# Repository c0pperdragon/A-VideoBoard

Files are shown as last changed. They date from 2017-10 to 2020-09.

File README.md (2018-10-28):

# A-Video Board

A small FPGA board with a component video interface to directly drive
an analog monitor or TV input.
Its main purpose is to create component video / RGB mods of vintage
home computers and consoles or to provide video output for hobby projects.

It consists of the purest minimum parts necessary to have a multi-purpose
FPGA combined with a simple way to generate a YPbPr signal. After much research
I finally settled on a cheap MAX 10 device in a TQFP-144 package which I can 
solder by hand (barely). The rest of the parts are pretty cheap and quite easy to solder. 

To interface any of the vintage systems to the A-Video Board, level shifters
are necessary to translate the 5 volt to 3.3 volt for the FPGA input pins. These level
shifters can be implemented in a system specific daughter board that can be stacked
on top of the A-Video board. Any such interface board can probably be implemented in a 
simple single-sided wide-pitch PCB that can be even home-etched with some experience.

Currently I have built applications of the A-Video board for 
* [Commodore 64](/c64mod)
* [Atari 8 bit machines](/atarimod)
* [ZX Spectrum](/zxspectrummod)

## Images
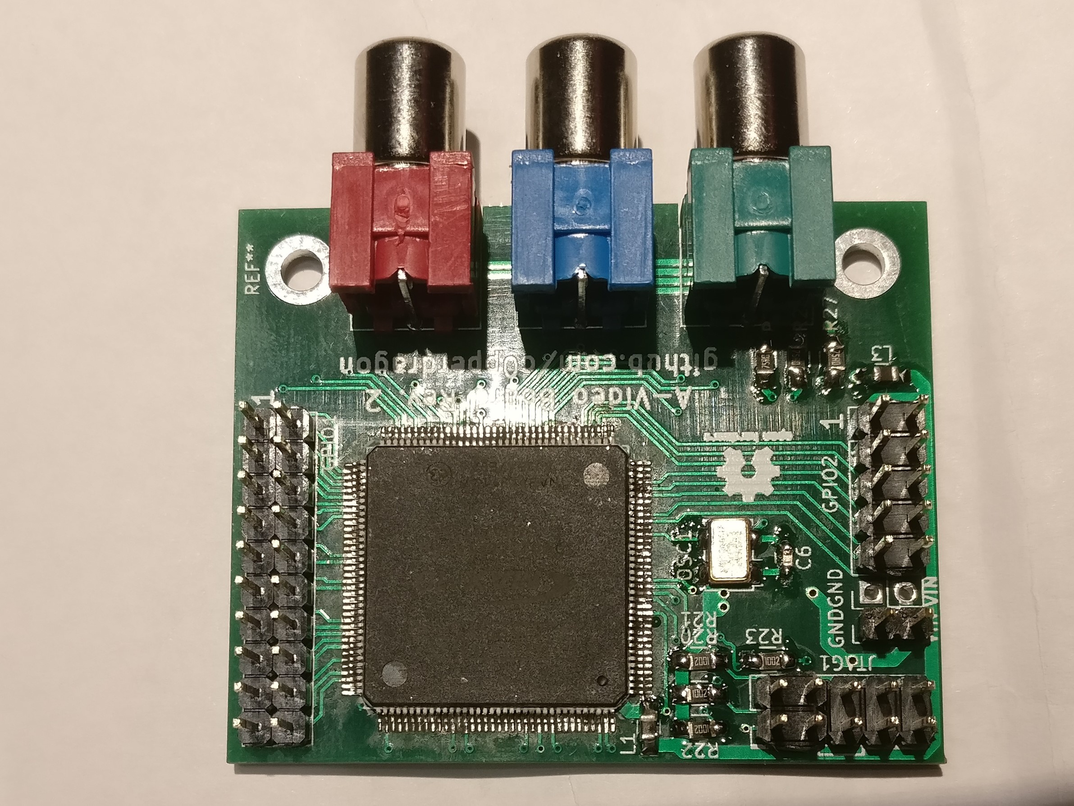
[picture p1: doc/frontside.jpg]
A-Video Board front

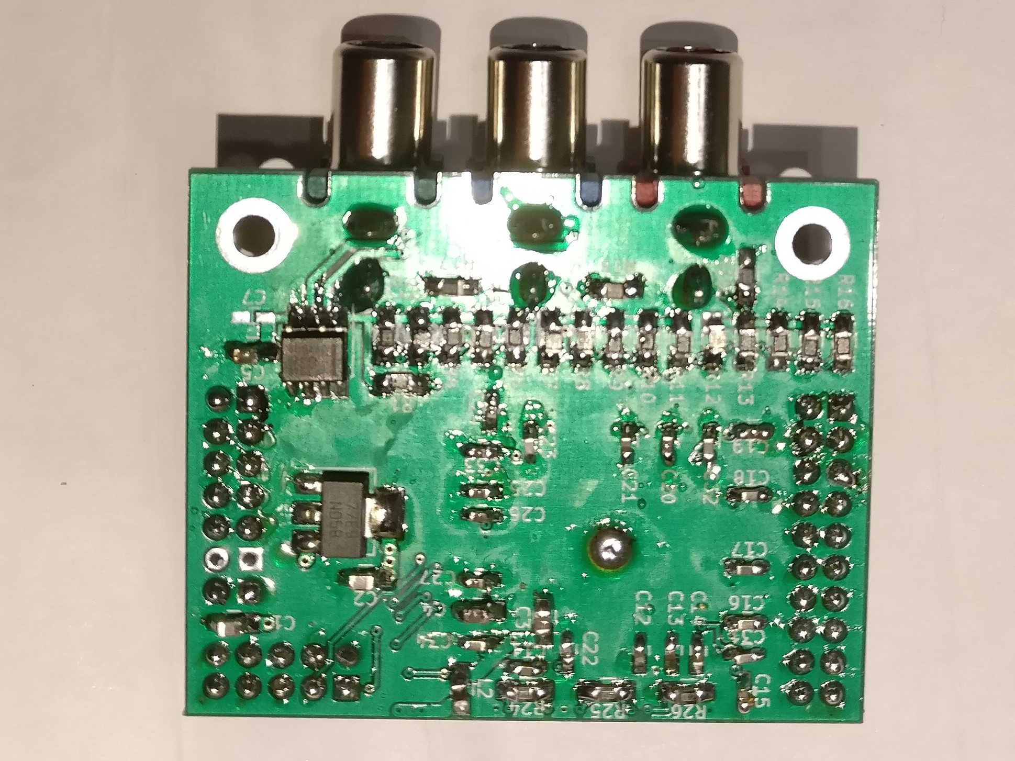
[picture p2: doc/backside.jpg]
A-Video Board back


## Board design

The board has these main parts

* 10M02SCE144: fairly cheap FPGA of the MAX10 series
* LM1117IMPX-3.3:   linear voltage regulator
* LFSPX0024957:     25Mhz clock generator
* THS7316:          video output amplifier
* R1-R19:           three 5-bit DACs made from transistors

and various supporting passive components, mainly decoupling, filtering and pull-ups.

It has the following connectors:
* GPIO1  20-pin header that directly connects to FPGA pins
* GPIO2  10-pin header with two pins providing GND and +3.3V, the remaining 8 connect to the FPGA.
* JTAG   10-pin header for programming the FPGA (via an USB-Blaster or compatible device)
* 3 RCA sockets to output the video signal (normally YPbPr, but other formats could be produced as well).
 Note that in the schematics these sockets are denoted as BNC, but are actually RCA connectors of type 
 RCJ-046 (green), RCJ-042 (red), RCJ-045 (blue).
* GND, VIN  Provide between 4.5V and 9V as supply voltage. The board consumes about 80mA.
 
## Contact
If you plan to use an A-Video board, feel free to contact me for assistance:
reinhard.grafl (at) aon.at  
Maybe I will either have some spare PCBs I could send you to populate yourself,
or even provide you with a fully assembled board for the cost of the parts and shipping.

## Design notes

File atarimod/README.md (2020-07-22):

# Atari RGB Mod

Built on the A-Video board, this is a modification usable for Atari 8-bit 
computers that generate YPbPr signal in either 288p or 576p to display on
modern displays. 

## Motivation

These old Atari computers generate the colour output signal directly in the weird way that was
necessary to construct a PAL or NTSC signal. The technique is called "quadrature amplitude modulation" and has the
disadvantage of not being completely reversible, so the original colours can not be reconstructed from this
signal.
Even worse, the XL line of machines does not even provide this signal directly on the video output, but
only already combined with the luminance signal as composite video. There are simple ways to provide 
separate luminance and colour, but even then the quality is pretty bad. 
This was not such a problem on cathode ray tube (CRT) displays, but on modern LCD TVs this signal looks totally
unusable.

So, no matter how I tried, I could not reliably re-construct the original colours from the colour signal output. 
The only way to really solve the issue was to intercept the necessary information in digital form to 
create a perfectly sharp and clear analog video signal by my own circuitry. 

## Theory of Operation

The FPGA chip passively listens to all relevant pins of the GTIA graphics chip and re-implements the 
relevant logic of the GTIA in its logic fabric, effectively providing a second GTIA (parts of it).
To sniff the signals from the GTIA, a specific adapter board is needed that sits between the 
GTIA and its socket. Revision 3 of the adapter is now pretty small and should fit in all Atari models.
From this adapter, a 20-pin ribbon cable (either mounted permanently to the adapter or using a plug)
leads to the FPGA board.
This FPGA board can either be the generic A-Video board or a re-purposed C64 Video Enhancement Board. 
Both boards are firmeware-compatible, but differ in their size and connector options. You should 
also be able to fairly easily change these connectivity options anyway.

## Adapter building details (Rev. 3)

In the doc folder, there are schematics, gerber files and a bill of material to build the adapter.
Ideally you need a 0.8mm PCB (a slighly thicker boards will also work) and assemble everything except
the P1 socket.  This specific socket is meant to be put into the big holes, so the extra-long solder tails 
will stick out pretty far on the bottom side. These will then fit into the IC socket on the Atari.
Take care not to get any solder onto these thin tails when soldering the ticker barrels into the 
adapter board (this can become tricky, but with a 0.8mm board it should not be too hard).
Before actually soldering the socket you have to cut away one of the plastic cross-beams so it
will not conflict with the ICs.

For attaching the 20-pin ribbon cable to P2, you have several options. I used an angled 
pin-header with a standard ribbon cable connector to keep a low profile. If there is space 
in your device you can as well use a straight pain-header. An even more sophisticated option
is a permantent PCB-to-ribbon-cable header which can be found with quite a low profile.
You can even solder the ribbon cable wires direcly into the board or whatever you fancy.

## FPGA Details

The FPGA on the A-Video board is programmed in VHDL, using the free version of the Quartus II development suite.
This chip has an on-board non-volatile program memory, so no external flash is needed and the chip has
a very short start-up time. There is a PLL built in which I use to generate a 228Mhz clock from the 25Mhz reference.
With this 228Mhz and some advanced  programming I can multiply the Atari pixel clock to a pretty clean (below 1 ns jitter) 14,1875 MHz clock to drive the whole circuit and create a nice output signal.

On non-PAL machines the Atari pixel clock runs at a slightly different speed. There the clock multiplier circuit will actually produce an internal clock that has variations in their clock cycle length. This will lead
to a slightly different length of every other pixel in 240p mode, and of every 4th pixel in 480p mode.

## Output

The mod can be used to create three different output formats:
* 240p/288p  (default)
* 480p/576p
* 480p/576p with scanline effect 

Selecting the output can be done by jumper connectors or an external switch (already provided 
in the C64 Video Enhancement):
* Connect GPIO2_4 to GND: 480p/576p
* Connect GPIO2_5 or GPIO2_6 to GND: 480p/576p with scanline effect

## Images
Installation of the two mod boards (Adapter Rev.2)
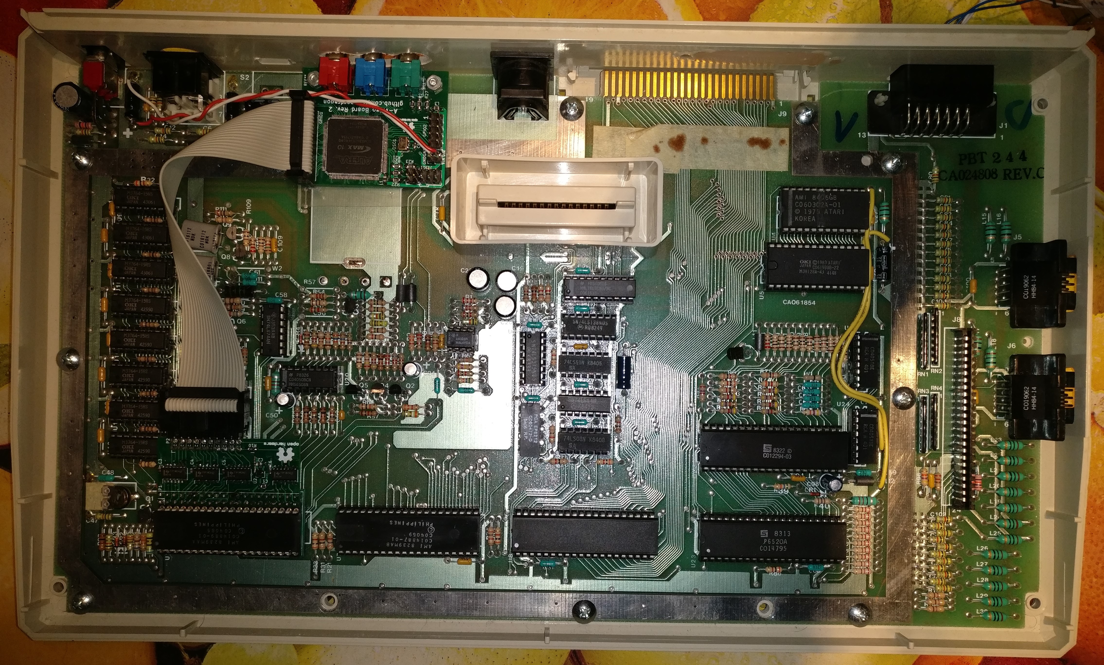
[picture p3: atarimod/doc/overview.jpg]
Overview over the whole system


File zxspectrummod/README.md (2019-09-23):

# ZXSpectrum Mod

Built on the A-Video board, this is a modification usable for the
ZX Spectrum 16K/48K versions (li'l old Speccy) that generates a
YPbPr signal in either 288p or 576p to display on modern displays.

## Motivation

As many home computers of the era, the ZX Spectrum (16K,48K) generates its
video output in the form of a composite signal that was of notoriously
bad quality, even if viewed on an analogue cathode ray tube. With 
modern LCD screens that do some digital preprocessing of the signal,
the result is even more horrible.
Even though the graphics chip (the ULA) outputs the video signal 
as a kind of RGB signal (YUV for these who know their colour formats), this
signal is still very noisy and there is a lot of digital processing
that shows up in the image. 
So this machine was also a good candidate for improvement with
my A-Video board. 

## Building

The construction uses the A-Video board with a small daughter board for shifting
the logic levels from 5V to 3.3V. 
To avoid soldering leads directly to the ULA, I took the
signals from various via points on the board - basically wherever I could
find one. In a few instances I soldered the leads to some other pins of 
various parts - but never to the ULA itself.

You may notice that the mod just fits into the tiny space that is
left in the ZX Spectrum after removing the RF modulator. That is no coincidence. 
The design of the A-Video board itself was totally driven by this exact space
constraint. 

As a side note I want to mention that I have replaced the original 
voltage regulator with its huge heat sink with a modern buck converter 
that generates nearly no heat at all. This will probably reduce the stress on the 
power supply (the original one) as well reduce the temperature in the cramped 
computer case.

## Implementation details

The FPGA chip passively listens to all relevant pins of the ULA and tries to make
sense of what is going on. 
This was not so easy as it may seem, because I was not able to directly extract the pixel
clock. There are no pins on the ULA that would directly provide this. The connection to the 
oscillator quartz is very sensitive to any added load and I could not reliably connect anything
to it without rendering the system unstable. I could also not use the clock output to the CPU 
because the ULA turns this on and off in a totally unpredictable pattern to disable CPU
access to the bus.

I figured out that it is possible to listen to the CAS line which is driven by the ULA to fetch
image data from the memory. All ULA accesses have a very distinct timing pattern and can be well
separated from the accesses that are done on behalf of the CPU. For every 8 pixels that are drawn
on the screen, the ULA fetches two bytes from the same memory row without re-sending the row
address. The FPGA always monitors these bytes and can re-construct the contents of the 
video RAM. 

With a kind of custom PLL-circuit done in the FPGA, I can generate a video output signal that
is in sync with the incoming stream of video data.

## Output

The mod can be used to create three different output formats:
* 288p (default)
* 576p
* 576p with scanlines

Selecting the output can be done by jumper connectors or an external switch:
* Connect GPIO1_18 to GPIO1_17 (or GND): 576p without scanlines
* Connect GPIO1_15 to GPIO1_17 (or GND): 576p with scanlines 

## Images
Overview over the whole system
Installation of A-Video with daughter board
Closed machine with YPbPr sockets
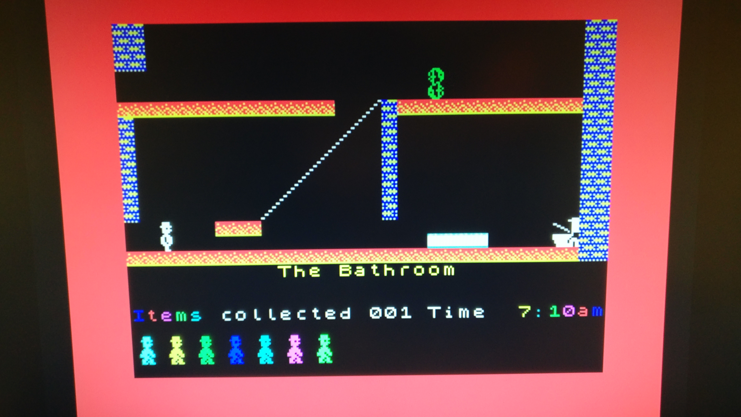
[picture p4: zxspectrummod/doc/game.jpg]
576p video output on my TV

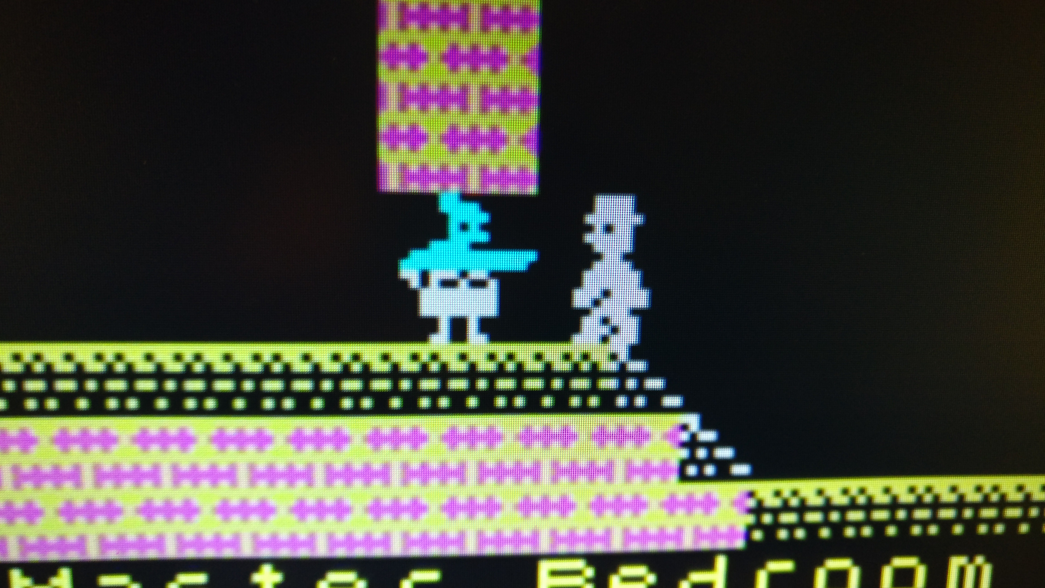
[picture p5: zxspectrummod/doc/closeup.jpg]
Closeup of video output


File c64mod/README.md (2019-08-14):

# C64 RGB Mod

Built on the A-Video board, this is a modification usable for the Commodore 64 computer
that generates a YPbPr signal in either 288p or 576p to display on modern displays.

## Motivation

I wanted to get the most perfect display from an original C64 computer. After many failed attempts to 
reconstruct a digitally perfect pixel-by-pixel display from the S-Video output, I finally came back
to my original idea to emulate the inner workings of the VIC-II chip. 
So, as for the atari 8-bit line and the ZX Spectrum, I applied my trusty A-Video board. 

## Building details

The FPGA chip passively listens to all relevant pins of the VIC graphics chip and re-implements the 
relevant logic of the GTIA in its logic fabric, effectively providing a second VIC (parts of it).
The mod board consists of two parts: A small adapter board that sits under the VIC and sniffs all relevant
pins, and the A-Video board that does the actual processing. The 5 volt signals from the C64 are
level-shifted by the adapter board down to 3.3 volts for use by the FPGA.
Since the adapter board only listens to the signals (with very high-impedience input pins), it 
will not influence the working of the VIC or any other part of the system in any way. The FPGA implementation
may have some glitches, but this should only affect the visual output.
Note that the mod consumes an additional 100mA of current from the 5 volt rail, 
so make sure that your power supply can handle this.

## Assembling the VIC adapter board

If you want to build your own adapter board, you need to have a PCB manufactured with 0.8mm thickness 
(use the gerber.zip for ordering). After soldering the ICs and passives, you need to fit a 40-pin
IC socket into the big holes. Use the socket type with round pins (the more expensive ones).
Solder from below and remove as much excess solder as possible. Then install the ribbon cable connector.
Take special care when installing the voltage regulator, as this small package always gave me the most trouble.
For your convenience, I have set up a [BOM](doc/adapterboard_bom.ods) and a parts list at 
[mouser](https://www.mouser.com/ProjectManager/ProjectDetail.aspx?AccessID=2b75b16750)
containing everything to build the board.

## Connectors

In my current build, the A-Video port is just screwed on top of the existing RF modulator.
This saved me the trouble of removing the modulator first (which would need additional circuitry to
keep the A/V output working). But this comes at the cost that the back of the computer case 
now has a rather large and ugly hole. I am pretty sure there are good solutions available to get rid of
this big modulator box while keeping the A/V functionality. Then the YPbPr connectors would be located
much lower and would look more natural.
If you even want a totally reversible mod you could probably place the A-Video board somewhere inside the
case and bring out the YPbPr cable through the user port opening.

## Output

The mod can be used to create three different output formats:
* 288p (default)
* 576p
* 576p with scanline effect

Selecting the output can be done by jumper connectors or an external switch:
* Connect GPIO2_4 to GPIO2_2 (GND): 576p
* Connect GPIO2_6 to GPIO2_2 (GND): 576p with scanline effect

## Images
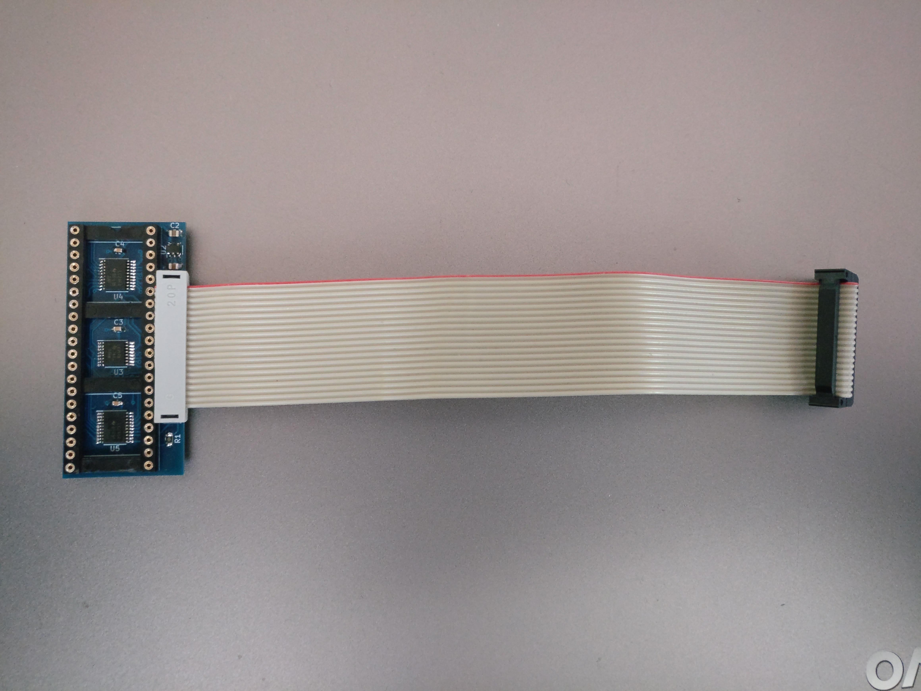
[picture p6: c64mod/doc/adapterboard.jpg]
VIC-II adapter board

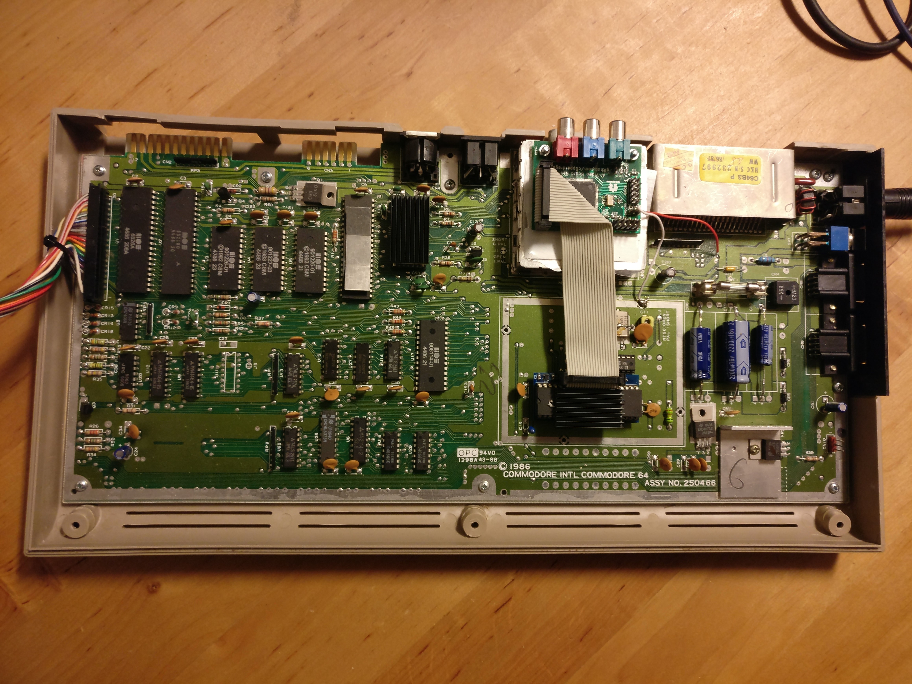
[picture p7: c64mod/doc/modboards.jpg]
Installation of the two mod boards

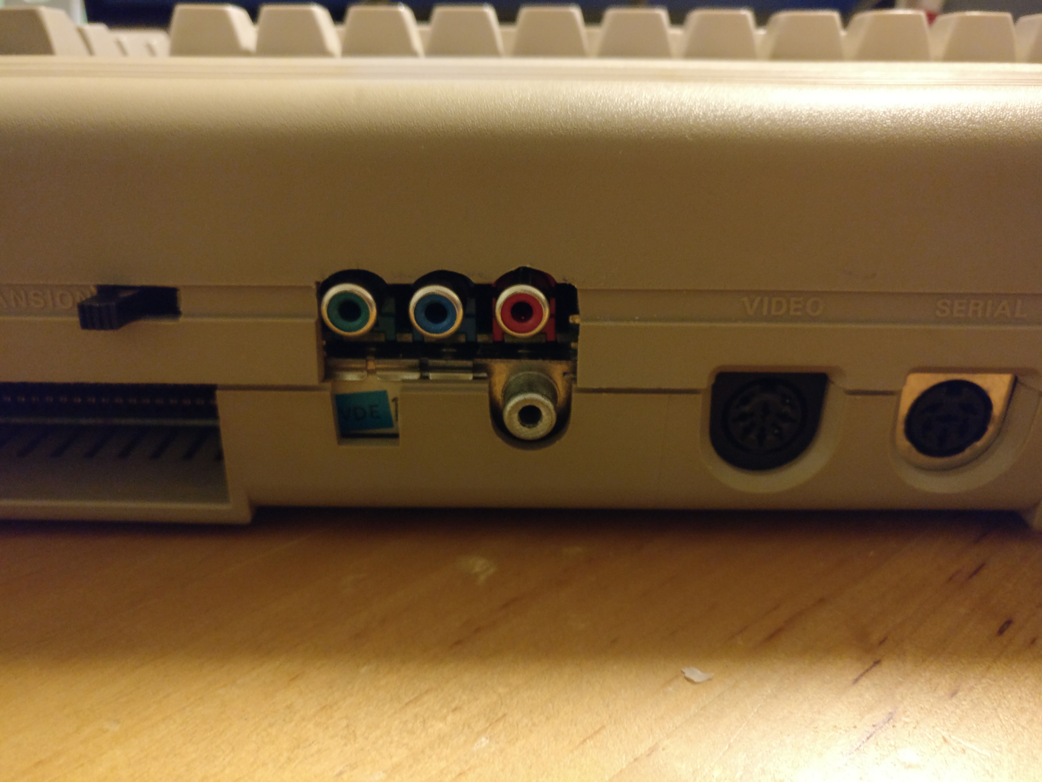
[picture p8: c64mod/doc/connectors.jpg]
Backside connectors

Display with standard definition (crappy upscaler)
Display with doubled scanlines
Display with doubled scanlines and visual scanline effect

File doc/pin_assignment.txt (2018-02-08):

Pin assignments for the A-Video Board (Rev.2)

25Mhz Reference clock:   MAX 10 pin 25

20-pin GPIO-header GPIO1
Connector pin            MAX 10 pin       
GPIO1 1                  74
GPIO1 2                  75
GPIO1 3                  76
GPIO1 4                  77
GPIO1 5                  78
GPIO1 6                  79
GPIO1 7                  80
GPIO1 8                  81
GPIO1 9                  87
GPIO1 10                 88
GPIO1 11                 91
GPIO1 12                 92
GPIO1 13                 97
GPIO1 14                 98
GPIO1 15                 99
GPIO1 16                100
GPIO1 17                101
GPIO1 18                103
GPIO1 19                105
GPIO1 20                106

10-pin GPIO-header GPIO2
Connector pin            MAX 10 pin       
GPIO2 1                  3.3V
GPIO2 2                  GND
GPIO2 3                  41
GPIO2 4                  40
GPIO2 5                  39
GPIO2 6                  33
GPIO2 7                  32
GPIO2 8                  31
GPIO2 9                  28 (can drive PLL)
GPIO2 10                 27 (can drive PLL)

In-board wiring of the MAX 10 to the DAC
                         MAX 10 pin
Y(5) = SYNC              46
Y(4)                     47
Y(3)                     48
Y(2)                     49
Y(1)                     50
Y(0)                     51
PB(4)                    52
PB(3)                    53
PB(2)                    59
PB(1)                    60
PB(0)                    61
PR(4)                    63
PR(3)                    65
PR(2)                    67
PR(1)                    69
PR(0)                    70

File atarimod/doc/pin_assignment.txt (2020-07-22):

Pin assignments for the Atari mod

GTIA pin      Mod board out   A-Video board     MAX 10 pin
A1            P2 1            GPIO1 1           74
A2            P2 2            GPIO1 2           75 
A0            P2 3            GPIO1 3           76
A3            P2 4            GPIO1 4           77
D3            P2 5            GPIO1 5           78
A4            P2 6            GPIO1 6           79 
D2            P2 7            GPIO1 7           80 
D4            P2 8            GPIO1 8           81 
D1            P2 9            GPIO1 9           87 
D5            P2 10           GPIO1 10          88
D0            P2 11           GPIO1 11          91   
D6            P2 12           GPIO1 12          92
AN0           P2 13           GPIO1 13          97
D7            P2 14           GPIO1 14          98
AN1           P2 15           GPIO1 15          99
RW            P2 16           GPIO1 16         100
AN2           P2 17           GPIO1 17         101
CS            P2 18           GPIO1 18         103
PHI2          P2 19           GPIO1 19         105
HALT          P2 20           GPIO1 20         106

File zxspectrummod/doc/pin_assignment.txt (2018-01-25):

Pin assignments for the ZX-Spectrum mod (Rev.2)

Mod board in   Mod board out    A-Video board       MAX 10 pin
D7             OUT1 1           GPIO1 14            98
D6             OUT1 2           GPIO1 12            92
D5             OUT1 3           GPIO1 10            88
D4             OUT1 4           GPIO1 8             81
D3             OUT1 5           GPIO1 6             79
D2             OUT1 6           GPIO1 4             77
D1             OUT1 7           GPIO1 2             75
D0             OUT2 2           GPIO2 3             41
CAS            OUT2 3           GPIO2 5             39
IOREQ          OUT2 4           GPIO2 7             32
WR             OUT2 5           GPIO2 9             28

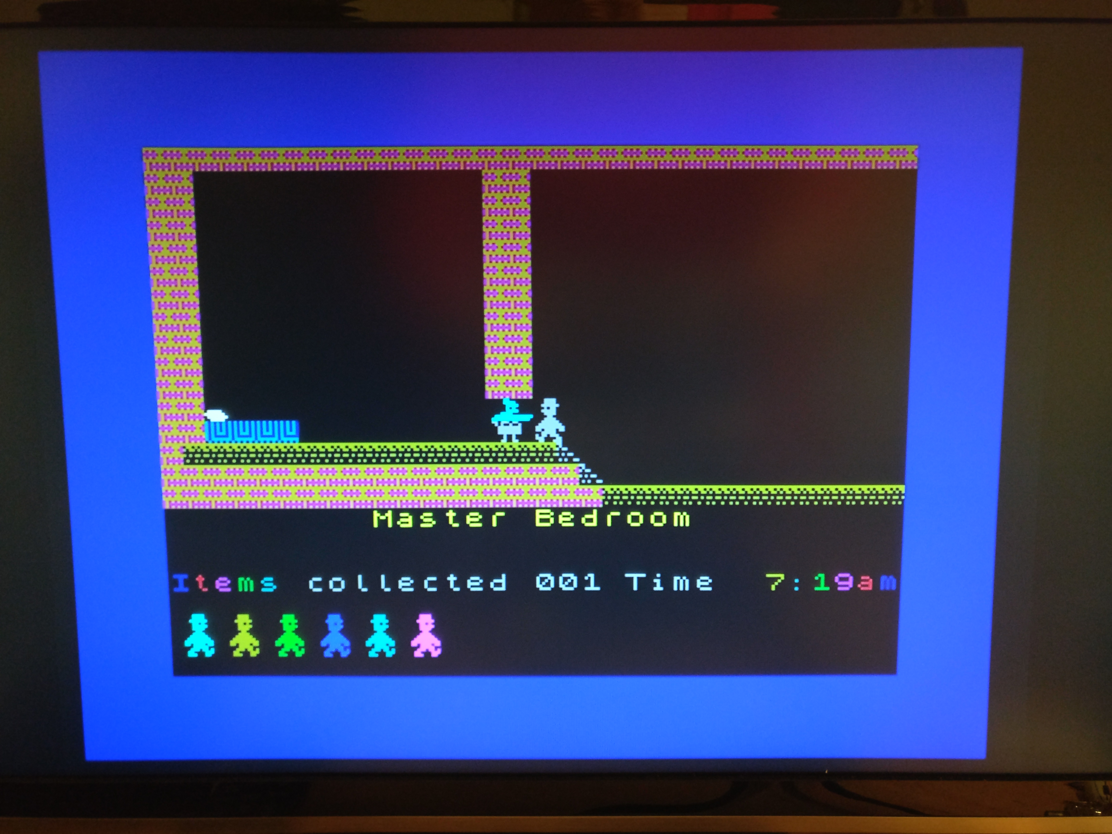
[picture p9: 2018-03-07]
zxspectrummod/doc/game288p.jpg

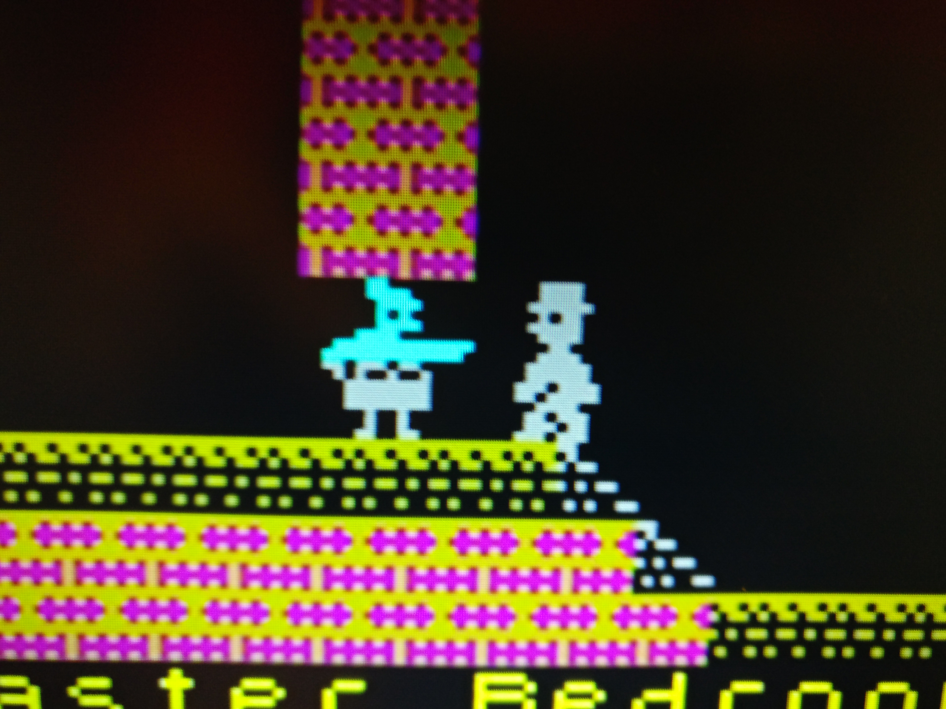
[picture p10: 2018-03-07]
zxspectrummod/doc/closeup288p.jpg

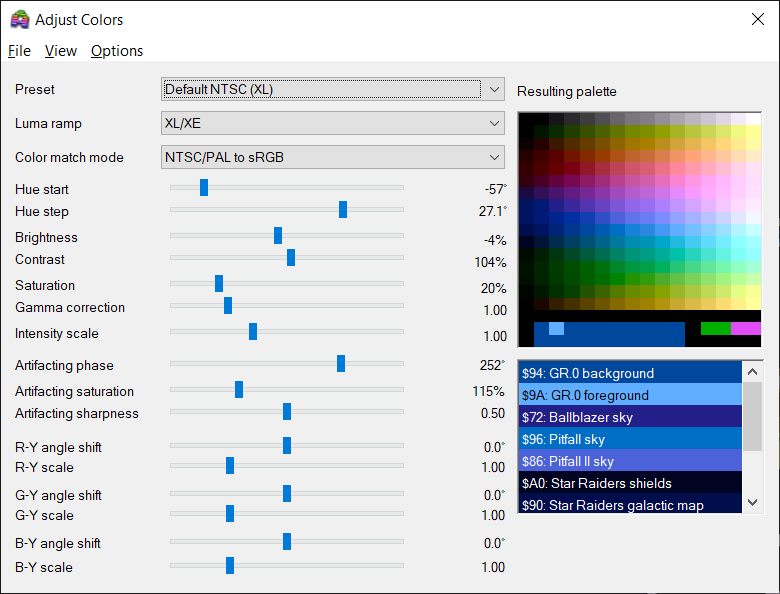
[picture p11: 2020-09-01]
atarimod/palette/Altirra Default NTSC.png

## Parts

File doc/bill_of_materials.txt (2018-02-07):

Reference, Value, Footprint, Datasheet
POWER1,CONM_01x02,Pin_Headers:Pin_Header_Straight_1x02_Pitch2.54mm,
C6,100nF,Capacitors_SMD:C_0603_HandSoldering,
C15,100nF,Capacitors_SMD:C_0603_HandSoldering,
C16,100nF,Capacitors_SMD:C_0603_HandSoldering,
C17,100nF,Capacitors_SMD:C_0603_HandSoldering,
C14,100nF,Capacitors_SMD:C_0603_HandSoldering,
C13,100nF,Capacitors_SMD:C_0603_HandSoldering,
C12,100nF,Capacitors_SMD:C_0603_HandSoldering,
C11,100nF,Capacitors_SMD:C_0603_HandSoldering,
C18,100nF,Capacitors_SMD:C_0603_HandSoldering,
C19,100nF,Capacitors_SMD:C_0603_HandSoldering,
C20,100nF,Capacitors_SMD:C_0603_HandSoldering,
C21,100nF,Capacitors_SMD:C_0603_HandSoldering,
C22,100nF,Capacitors_SMD:C_0603_HandSoldering,
C23,100nF,Capacitors_SMD:C_0603_HandSoldering,
C24,100nF,Capacitors_SMD:C_0603_HandSoldering,
C33,100nF,Capacitors_SMD:C_0603_HandSoldering,
C32,100nF,Capacitors_SMD:C_0603_HandSoldering,
C31,100nF,Capacitors_SMD:C_0603_HandSoldering,
C34,100nF,Capacitors_SMD:C_0603_HandSoldering,
C25,100nF,Capacitors_SMD:C_0603_HandSoldering,
U2,10M02SCE144,footprints:QFP_144_GND,
JTAG1,CONN_02X05,Pin_Headers:Pin_Header_Straight_2x05_Pitch2.54mm,
R23,10k,Resistors_SMD:R_0805_HandSoldering,
R21,10k,Resistors_SMD:R_0805_HandSoldering,
R20,10k,Resistors_SMD:R_0805_HandSoldering,
R22,10k,Resistors_SMD:R_0805_HandSoldering,
R24,10k,Resistors_SMD:R_0805_HandSoldering,
R26,10k,Resistors_SMD:R_0805_HandSoldering,
R25,10k,Resistors_SMD:R_0805_HandSoldering,
C1,10uF,Capacitors_SMD:C_0805_HandSoldering,
C2,10uF,Capacitors_SMD:C_0805_HandSoldering,
L2,10uH,Capacitors_SMD:C_0805_HandSoldering,
L1,10uH,Capacitors_SMD:C_0805_HandSoldering,
C3,10uF,Capacitors_SMD:C_0805_HandSoldering,
C4,10uF,Capacitors_SMD:C_0805_HandSoldering,
AMP1,THS7316,Housings_SOIC:SOIC-8_3.9x4.9mm_Pitch1.27mm,
R29,75,Resistors_SMD:R_0805_HandSoldering,
R28,75,Resistors_SMD:R_0805_HandSoldering,
R27,75,Resistors_SMD:R_0805_HandSoldering,
C7,100nF,Capacitors_SMD:C_0603_HandSoldering,
R16,16k,Resistors_SMD:R_0805_HandSoldering,
R15,8k,Resistors_SMD:R_0805_HandSoldering,
R14,4k,Resistors_SMD:R_0805_HandSoldering,
R13,2k,Resistors_SMD:R_0805_HandSoldering,
R12,1k,Resistors_SMD:R_0805_HandSoldering,
R19,150,Resistors_SMD:R_0805_HandSoldering,
R11,16k,Resistors_SMD:R_0805_HandSoldering,
R10,8k,Resistors_SMD:R_0805_HandSoldering,
R9,4k,Resistors_SMD:R_0805_HandSoldering,
R8,2k,Resistors_SMD:R_0805_HandSoldering,
R7,1k,Resistors_SMD:R_0805_HandSoldering,
R18,150,Resistors_SMD:R_0805_HandSoldering,
R6,16k,Resistors_SMD:R_0805_HandSoldering,
R5,8k,Resistors_SMD:R_0805_HandSoldering,
R4,4k,Resistors_SMD:R_0805_HandSoldering,
R3,2k,Resistors_SMD:R_0805_HandSoldering,
R2,1k,Resistors_SMD:R_0805_HandSoldering,
R17,150,Resistors_SMD:R_0805_HandSoldering,
R1,1k1,Resistors_SMD:R_0805_HandSoldering,
REG1,LM1117IMPX-3.3,TO_SOT_Packages_SMD:SOT-223,
GPIO2,CONN_02X05,Pin_Headers:Pin_Header_Straight_2x05_Pitch2.54mm,
C26,100nF,Capacitors_SMD:C_0603_HandSoldering,
C27,100nF,Capacitors_SMD:C_0603_HandSoldering,
POWER2,CONN_02X01,Pin_Headers:Pin_Header_Straight_1x02_Pitch2.54mm,
Y1,BNC,footprints:RCA_JACK,
PB1,BNC,footprints:RCA_JACK,
PR1,BNC,footprints:RCA_JACK,
GPIO1,CONN_02X10,Pin_Headers:Pin_Header_Straight_2x10_Pitch2.54mm,
OSC1,LFSPXO024957,Oscillators:Oscillator_SMD_EuroQuartz_XO53-4pin_5.0x3.2mm_HandSoldering,
L3,10uH,Capacitors_SMD:C_0805_HandSoldering,
C5,10uF,Capacitors_SMD:C_0805_HandSoldering,

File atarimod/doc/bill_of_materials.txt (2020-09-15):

References       Type                                                 Value/Part Number      Size

C1,C2            Ceramic Capacitor                                    1 uF                   2012 metric
C3,C4,C5,C6      Ceramic Capacitor                                    100 nF                 1608 metric
IC1,IC2,IC3,IC4  Schmitt-Trigger Inverter                             SN74LVC14ADBR          SSOP-14
P1               40-pin IC precision socket with long solder tails    111-93-640-41-001000   DIP 40
P2               Pinheader/Ribbon cable connector                     any                    2x20, 2.54mm 
R10              SMD Resistor                                         100 ohm                2012 metric
U2               LDO Voltage Regulator 3.3V                           MIC5504-3.3YM5         SOT-23-5

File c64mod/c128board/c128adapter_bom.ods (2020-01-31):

Manufacturer | Manufacturer Number | Designator | Qty | Description | Case | SMD/ TH | PCB side | Comments
Mill-Max | 111-93-640-41-001000 | U1 | 1 | IC & Component Sockets 40P LONG SOLDER TAIL |  | TH | Top | Unusual assembly
Mill-Max | 111-93-308-41-001000 | U1 | 1 | IC & Component Sockets 8P LONG SOLDER TAIL |  | TH | Top | Unusual assembly
Microchip | MIC5504-3.3YM5-TR | U2 | 1 | LDO Voltage Regulators Single 300mA LDO | SOT-23-5 | SMD | Top
Texas Instruments | SN74LVC257APWR | U3 | 1 | Multiplexer | TSSOP-16 | SMD | Top
Texas Instruments | SN74LVC245APWR | U4,U5 | 2 | Bustransceiver Tri-State Octal Bus | TSSOP-20 | SMD | Top
any |  | C1,C2 | 2 | Ceramic capacitor 10uF, 10%, 16V | 2012 | SMD | Top
any |  | C3,C4,C5 | 3 | Ceramic capacitor 100nF, 10%, 16V | 1608 | SMD | Top
any |  | R1 | 1 | Thick film resistor, 100 Ohm, 1% | 2012 | SMD | Top
HARTING | 9181209622 | J1 | 1 | PCB to ribbon cable connector 20P 2 ROW |  | TH | Top | Can also be other manufacturer
any |  |  | 1 | Ribbon cable, 20 leads, 1,27mm pitch, Length: 13cm |  |  | not on PCB
any |  |  | 1 | Ribbon cable connector, 20 pins (2x10) female, 2.54mm pitch |  |  | not on PCB | gold plated contacts if possible

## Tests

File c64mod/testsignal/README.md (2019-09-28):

Everything needed in a nice box

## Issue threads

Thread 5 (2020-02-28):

User feedback and experience

c0pperdragon, 2020-02-28:
Please let the community know how this device works for you, what the pitfalls were and maybe upload some pictures as well.

olliraa, 2020-03-01:
Just finished installing the A-videoboad into my ZX48k. My Speccy is an Issue 2 one with the following modifications/repairs:

-All caps replaced.
-A-videoboard installed and RF tank removed
-The infamous 7805 regulator replaced with a DC-DC step down converter pcb -> way less heat and more juice :)
-128k RAM with added GAL logic board -> this is 100% 128K Speccy compliant unlike the more simple "just add ram chips" mods. All RAM chips are also socketed now.
-vLA82 ULA replacement (original was somewhat broken)

The picture quality with the A-videoboard is simply amazing. My Speccy is connected to Sony BVM20F1E -> happy times :)

I just got the computer case closed (pun intended), which with the mod is kinda challenging, but doable. I'll add some pictures afterwards.

Just a few tips, how I solved some challenges. The original designer of the board kindly gave me some really good advice during my modding experience:

-Tap the D0-D7 signals directly from the RAM chips (pin 14) respectively. D7 is the left most chip.
-I tapped the WR, IQREQ and CAS signals directly from the ULA *under* the pcb = socket solder points. There's enough room fr the wires to go around the pcb back and actually the wire length is exactly the same as when tapping these signals from top of the pcb. Not the prettiest solution, but secure and solid :)

Closed 2022-12-13.

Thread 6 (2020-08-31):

TRRS suggestion

IanSB, 2020-08-31:
The TRRS option used on the C64 board works well so it might be worth replacing the three RCA connectors on the A VideoBoard with multiple TRRS connector positions wired in parallel so you can choose where to fit the TRRS connector depending on the position of the modultator output.

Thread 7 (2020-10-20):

Atari 5200

Icelvlan88, 2020-10-20:
Hello,

I see the Atari 5200 Sophia RGB is compatible with Atari 400, not sure if it a different board than the 5200 one. Do you think yours is compatible with 5200?

c0pperdragon, 2020-10-20:
I am pretty sure this should work. The 5200 is basically identical to the other machines of the 8-bit series in regards of its video system.

Icelvlan88, 2020-10-20:
Can this board output RGBs? Is it the same as the c64 board or this is something completely different?

c0pperdragon, 2020-10-22:
The A-Video board, when running the Atari firmware, can be jumpered to output RGsB. This may be already anough for you if your monitor can accept RGsB instead of RGB (most do ignore the sync pulses on the G line without problem) and you can additionally use the standard composite video signal as sync source.

If you have more specific demands on your signals, you can also desolder R1 from the FPGA board. This removes the sync signal from the G line and you can instead directly grab the pure sync pulse from the solder pad of R1 located nearer to the FPGA. It is a 3.3V level signal, so it should be compatible with anything that accepts TTL levels.

Icelvlan88, 2020-10-23:
I thought TTL was 5V is there a way to make the voltage higher? also this is a different board than c64 board correct?

c0pperdragon, 2020-10-23:
Oops - I was mistaken. The Atari mod firmware does not support RGsB at all. It will only ever output YPbPr.
There is a jumper option to output a very different digital signal for use with the RGBtoHDMI upscaler, but this is no use for a direct connection to an RGB monitor.

The A-Video board hardware itself is basically identical to the C64 component video mod board. It only has different output connectors (RCA instead of TRRS) and lacks the analog circuit needed for the C64.  So you can easily use a C64 mod for the Atari when flashing the Atari firmware.

If you really, really, really want an RGB option, I could modify the firmware.

Icelvlan88, 2020-10-23:
I was considering trying to use this if it work for an Atari 5200. The reason I prefer RGB is the way it looks through the framemeister and I typically use Genesis 2 RGB cables which use TTL.

c0pperdragon, 2020-10-24:
So I guess, it is your intention to build a Genesis 2 - compatible A/V port into your atari 5200. This is a pretty cool idea to re-use the rest of your setup.

When your genesis cable has the usual 470 Ohm attenuation resistor for the csync line, it will happily accept any digital sync signal between 2V and 7V. Below the 2V the sync may no longer be reliably detectable and above 7V it may become dangerous to the receiver.  With a 3.3V digital sync signal you are absolutely fine here.

A second matter are probably the 75 Ohm attenuation resistors that also seem to be built into the cable on the R, G, B lines. I am not sure about this, but the schematics for the cable I quickly found all have these.  So to avoid the picture to be to dark you would need to bridge the 75 Ohm resistors on the FPGA board to compensate for that.
It seems that the genesis console ommited the usual 75 Ohm output driver resistors which where then built into the cable.

I am positive now that I will actually add an RGsB output mode to the firmware anyway for exactly this kind of use cases.

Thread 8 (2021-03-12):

Test pattern

Zer02dk, 2021-03-12:
How is the test pattern suppose to look?
Mine looks strange, any ideas what could be the issue?

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

c0pperdragon, 2021-03-12:
The top left should be a rectangle with the 256 lum/hue combinations of Atari machined. Then there is a bar with the 16 colors of the C64. Then some moving lines. Below are three gradients with 32 steps each. One for Y one for Pb, one for Pr.
In your image it seems that all your DAC resistor networks are completely wrong/unsoldered/shorted. Or your monitor has a digital input.

Zer02dk, 2021-03-12:
I forgot to mention I'm using the RGBtoHDMI by hoglet67. But it could very well be my SMD soldering skills.

c0pperdragon, 2021-03-12:
OK, this is a completely different matter then.
The RGBtoHDMI can not convert just any analog YPbRP or RGB signal to HDMI. Basically it needs to get this in a kind of digitial or quantized form very specific to the machine in question.
This test pattern generator is just for use with "normal" YPbPr displays and will not work with the RGBtoHDMI.

I you use the A-VideoBoard in one of my supported machines (C64/C128, Atari 8bit, ZX Spectrum), then it can be configured (with jumper links) to generate such a quantized output signal. I guess there is no proper documention on this feature in the projects yet. Tell me which machine you are using the board and I can give you better instructions.

Zer02dk, 2021-03-13:
Ah, Im installing it in a C64. My bord is the one from your "C64-Video-Enhancement" project.
I havent installed it yes i wanted to test the bord first. But let me try and install it first. Just need to desolder that VICII chip.
Would you be intrested in my excess bare PCB's? I have 4 sets.

c0pperdragon, 2021-03-13:
Thank you, but I don't intend to build any more of these sets as they are now readily available from videogameperfection.com

About the testpattern: considering that you did the upscaling with the RGBtoHDMI this looks pretty OK. I would expect these kind of quantization result.

Zer02dk, 2021-03-18:
Finally got the C64 finished, and all seams to be working.

Closed 2021-03-18.

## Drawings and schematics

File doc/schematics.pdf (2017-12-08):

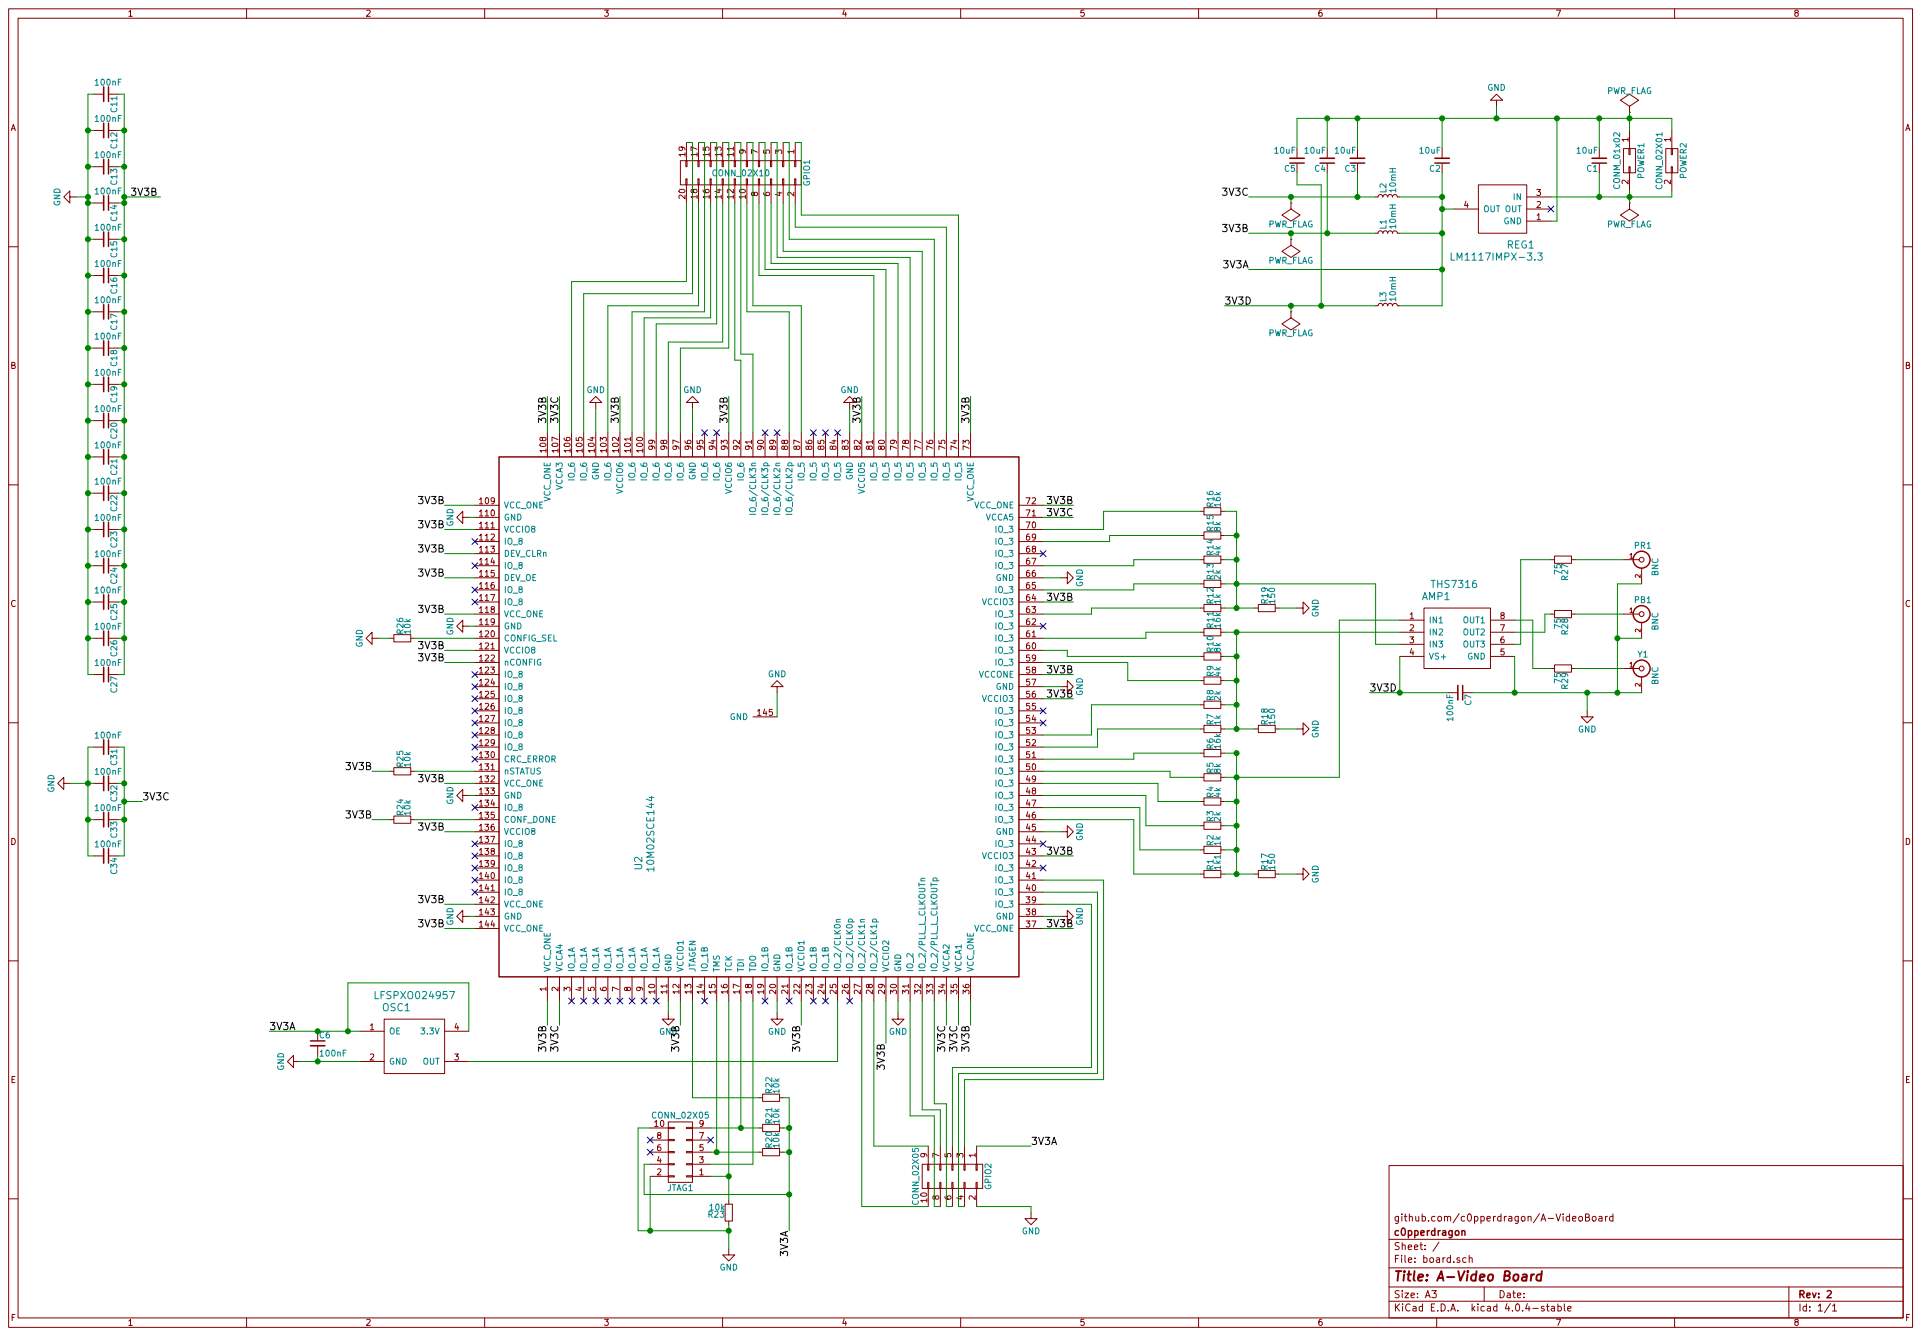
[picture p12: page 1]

File: board.sch Sheet: / c0pperdragon

Id: 1/1 Title: A-Video Board

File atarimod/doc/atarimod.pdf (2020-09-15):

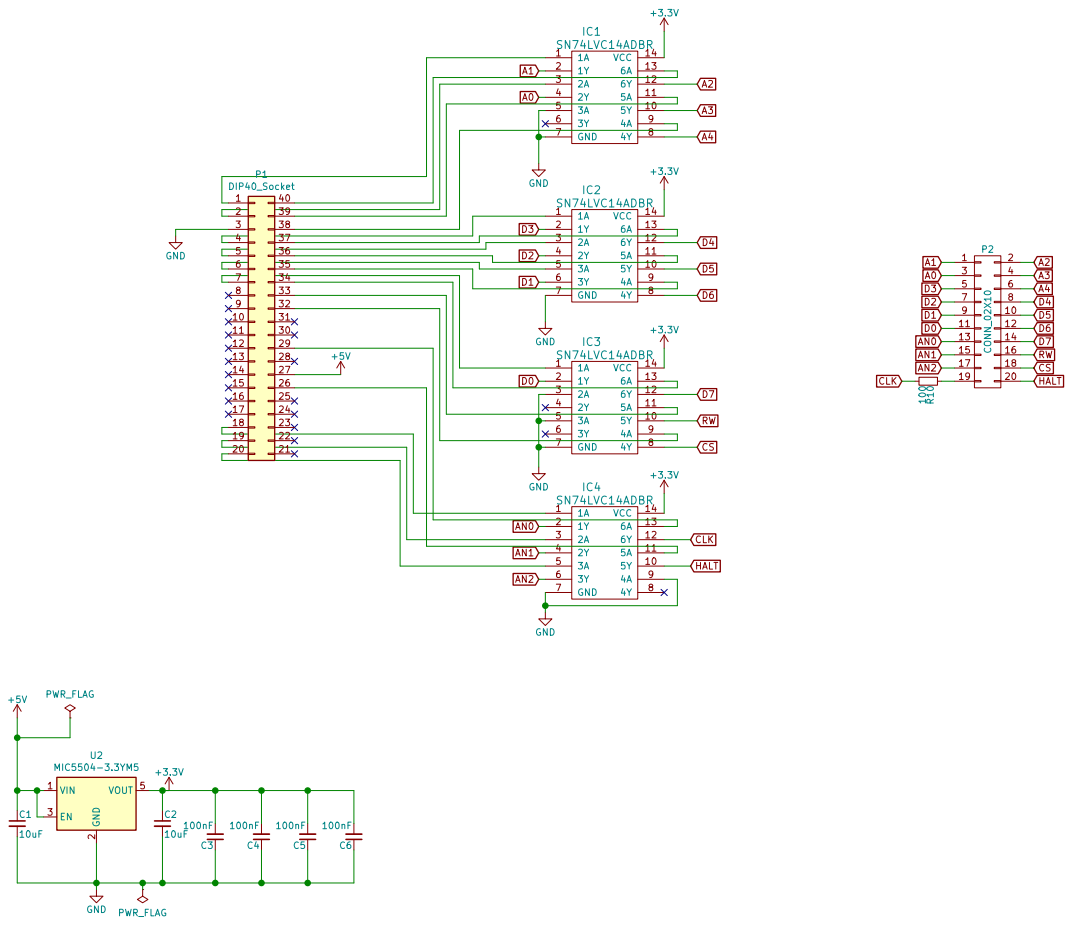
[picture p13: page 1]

+3.3V GND GNDGND GND GND

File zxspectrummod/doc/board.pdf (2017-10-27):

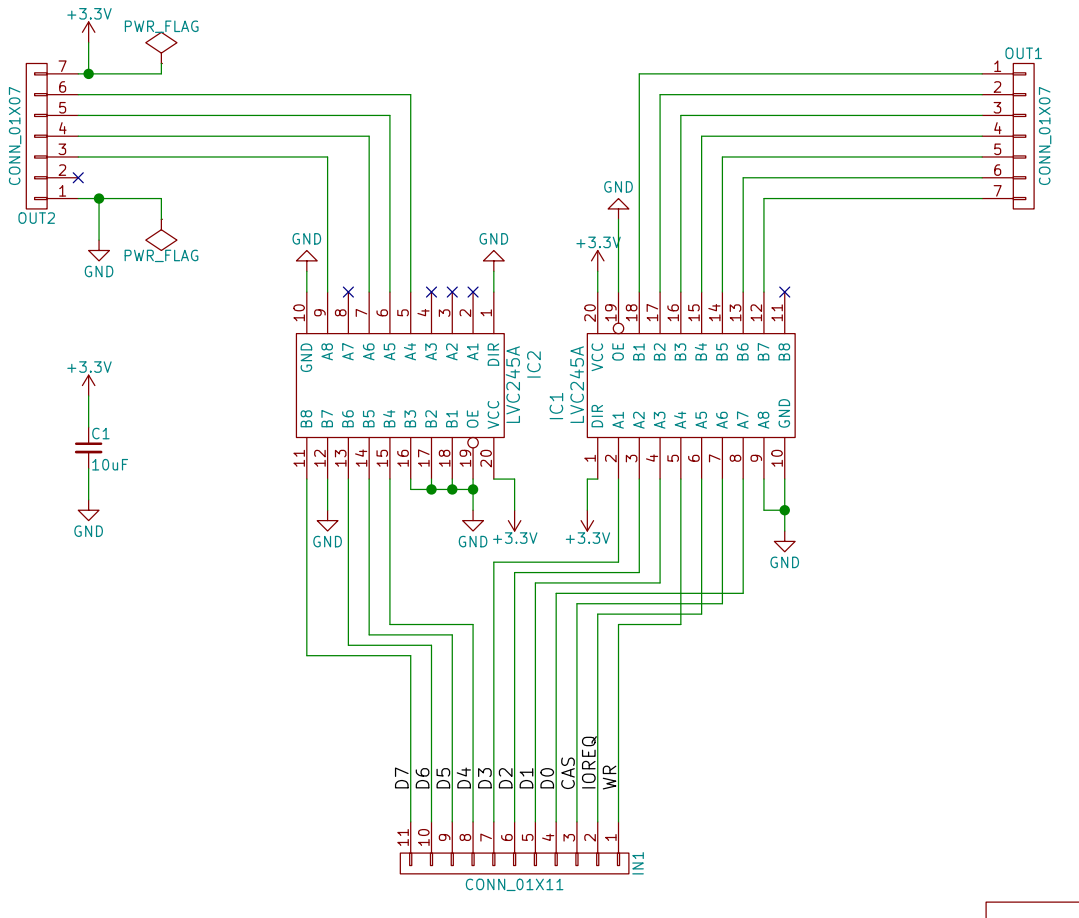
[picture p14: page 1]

9 GND 10 VCC 20 B8 11 B7 12 B6 13 B5 14 B4 15 B3 16 B2 17 B1 18 OE 19 IC2 LVC245A DIR

github.com/c0pperdragon/A-VideoBoard
File: board.sch Sheet: / c0pperdragon

Id: 1/1 Title: ZX Spectrum Mod

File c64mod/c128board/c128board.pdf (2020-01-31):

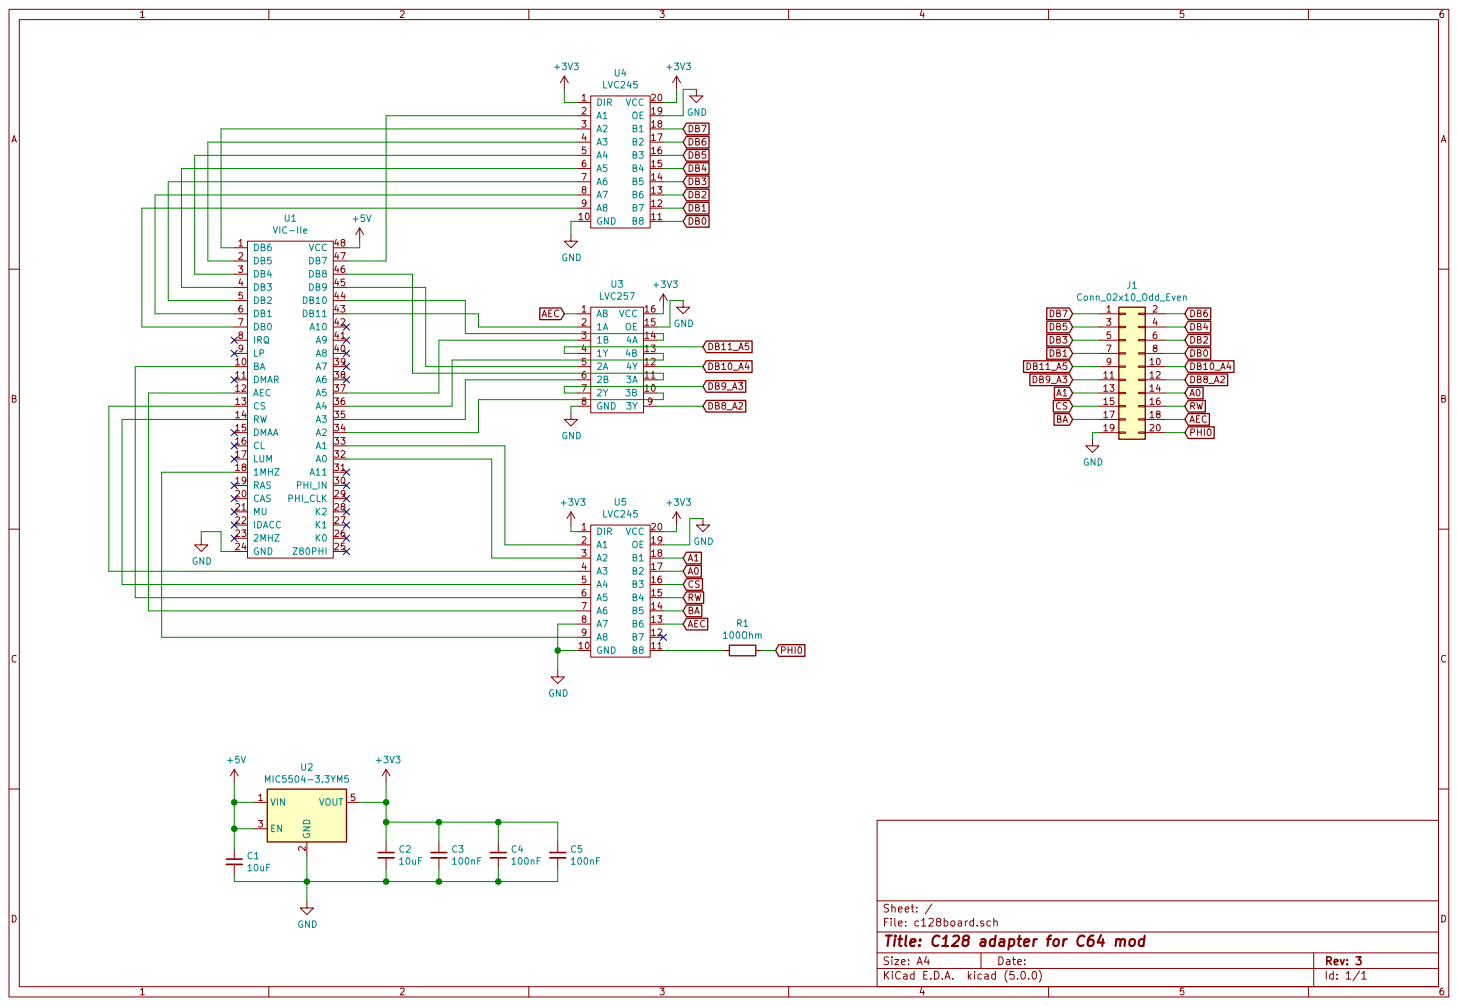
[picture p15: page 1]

2A 5 4Y | 12
2B 6 3A 3B | 11 10

Id: 1/1 Title: C128 adapter for C64 mod

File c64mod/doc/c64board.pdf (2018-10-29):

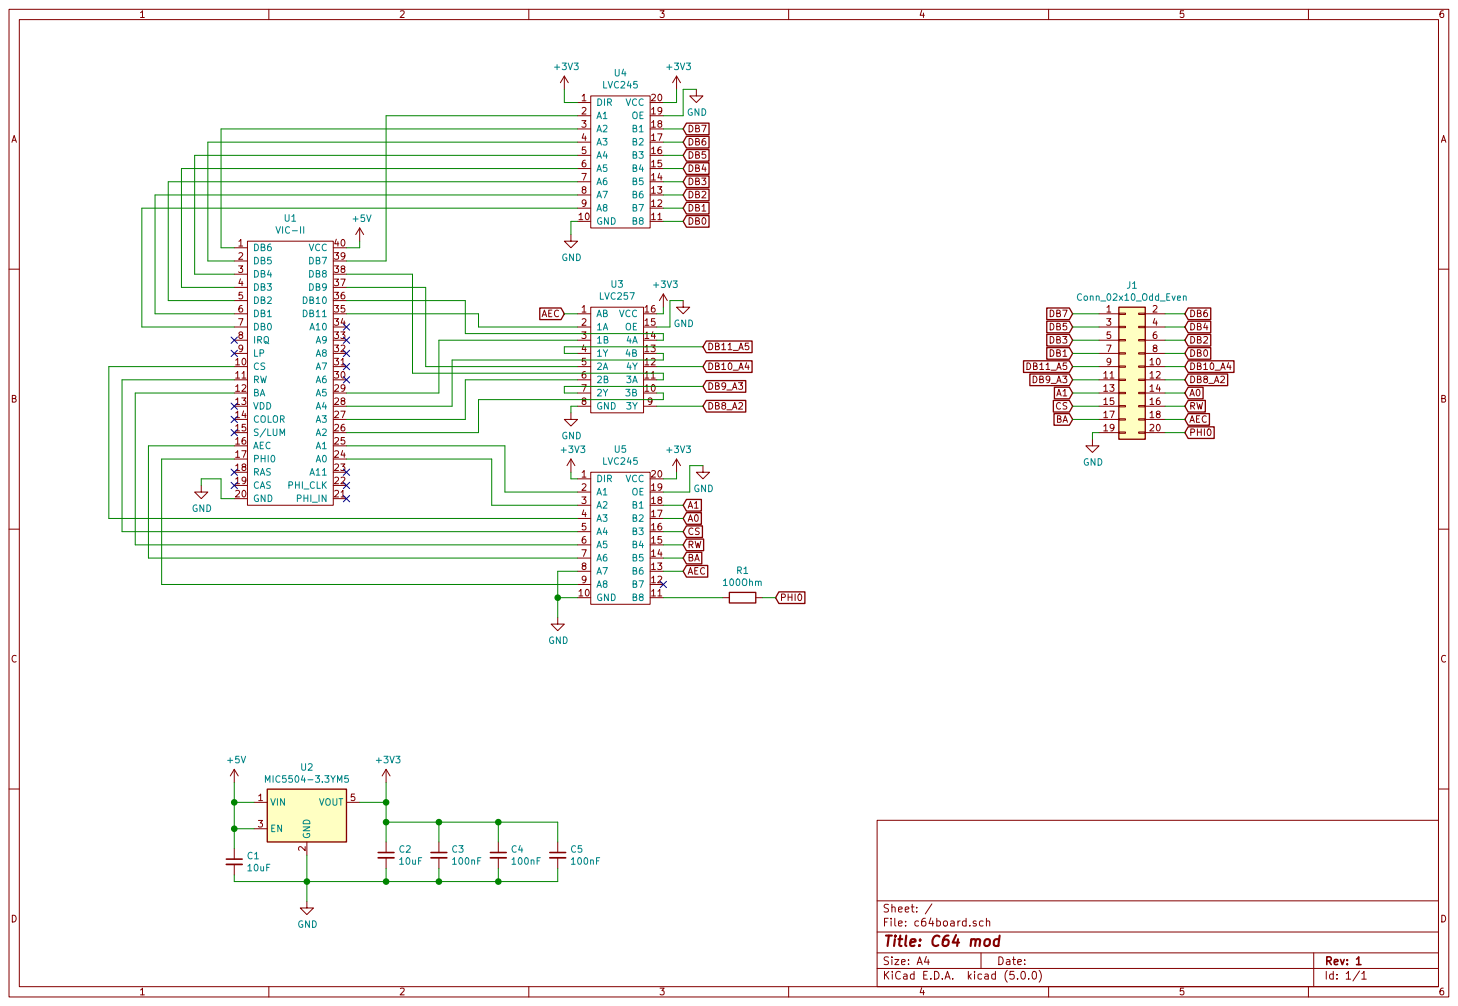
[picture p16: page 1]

2A 5 4Y | 12
2B 6 3A 3B | 11 10

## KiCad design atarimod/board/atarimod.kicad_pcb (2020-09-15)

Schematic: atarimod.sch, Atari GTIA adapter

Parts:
C1, C2: 10uF; C_0805_2012Metric_Pad1.15x1.40mm_HandSolder
C3, C4, C5, C6: 100nF; C_0603_1608Metric_Pad1.05x0.95mm_HandSolder
IC1, IC2, IC3, IC4: SN74LVC14ADBR; SSOP-14_5.3x6.2mm_P0.65mm
P1: DIP40_Socket; socket_embedded_40pin
P2: CONN_02X10; PinHeader_2x10_P2.54mm_Vertical
R10: 100; R_0805_2012Metric_Pad1.15x1.40mm_HandSolder
U2: MIC5504-3.3YM5; SOT-23-5

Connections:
+3V3: C2.1, C3.2, C4.2, C5.2, C6.2, IC1.14, IC2.14, IC3.14, IC4.14, U2.5
+5V: C1.1, P1.27, U2.1, U2.3
A0: IC1.4, P2.3
A1: IC1.2, P2.1
A2: IC1.12, P2.2
A3: IC1.10, P2.4
A4: IC1.8, P2.6
AN0: IC4.2, P2.13
AN1: IC4.4, P2.15
AN2: IC4.6, P2.17
CLK: IC4.12, R10.2
CS: IC3.8, P2.18
D0: IC3.2, P2.11
D1: IC2.6, P2.9
D2: IC2.4, P2.7
D3: IC2.2, P2.5
D4: IC2.12, P2.8
D5: IC2.10, P2.10
D6: IC2.8, P2.12
D7: IC3.12, P2.14
GND: C1.2, C2.2, C3.1, C4.1, C5.1, C6.1, IC1.5, IC1.7, IC2.7, IC3.3, IC3.5, IC3.7, IC4.7, IC4.9, P1.3, U2.2
HALT: IC4.10, P2.20
unnamed: IC1.1, P1.1
unnamed: IC1.3, P1.2
unnamed: IC1.9, P1.38
unnamed: IC1.11, P1.39
unnamed: IC1.13, P1.40
unnamed: IC2.1, P1.4
unnamed: IC2.3, P1.5
unnamed: IC2.5, P1.6
unnamed: IC2.9, P1.35
unnamed: IC2.11, P1.36
unnamed: IC2.13, P1.37
unnamed: IC3.1, P1.7
unnamed: IC3.9, P1.32
unnamed: IC3.11, P1.33
unnamed: IC3.13, P1.34
unnamed: IC4.1, P1.18
unnamed: IC4.3, P1.19
unnamed: IC4.5, P1.20
unnamed: IC4.11, P1.26
unnamed: IC4.13, P1.29
unnamed: P2.19, R10.1
RW: IC3.10, P2.16

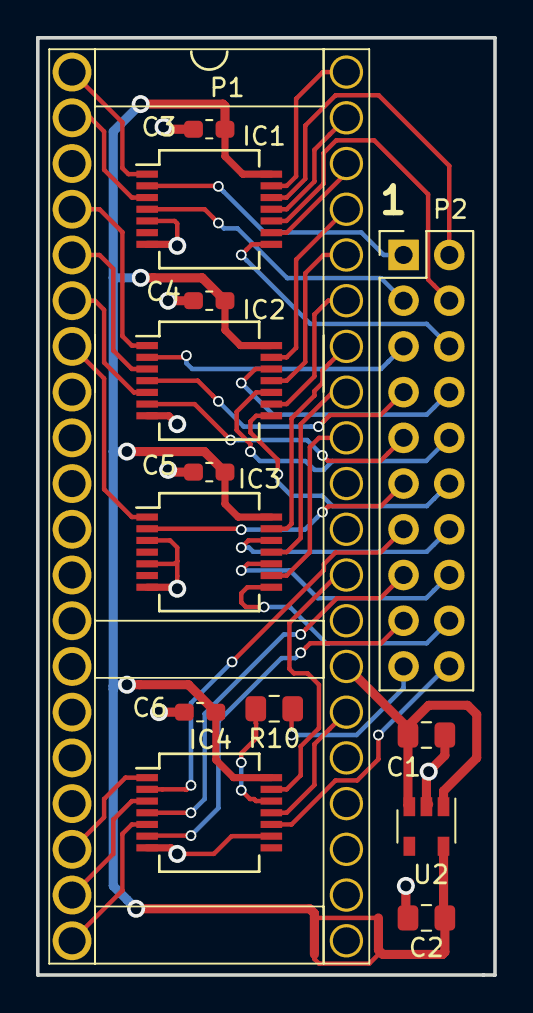
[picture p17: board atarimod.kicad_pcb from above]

Board: 2 copper layers, 25.4 x 52.1 mm, 14 parts (0 on the bottom side), 44 nets.

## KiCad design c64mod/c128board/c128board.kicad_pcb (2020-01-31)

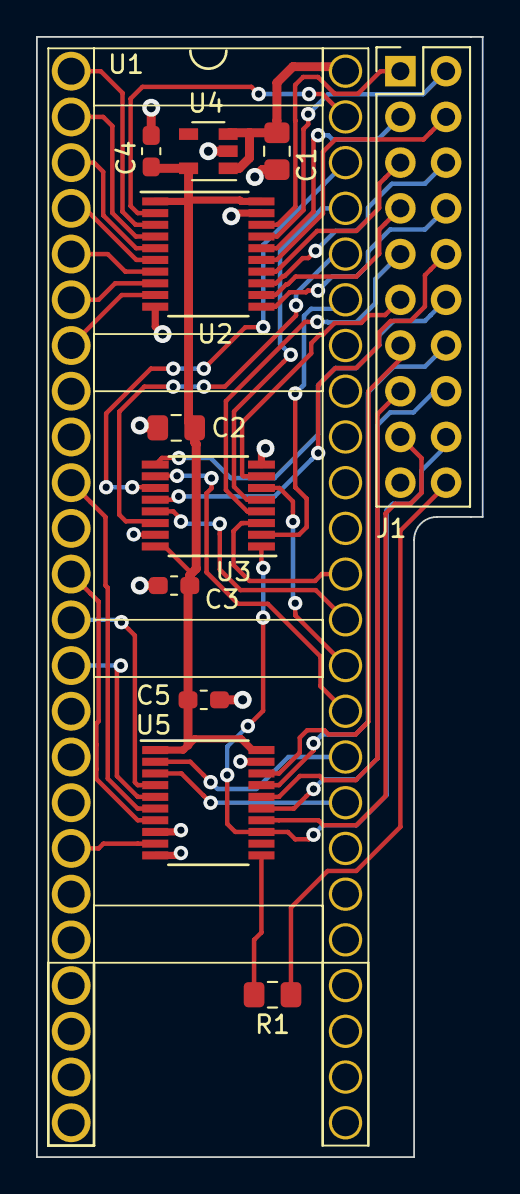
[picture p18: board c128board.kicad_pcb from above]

Board: 2 copper layers, 24.8 x 62.2 mm, 12 parts (0 on the bottom side), 46 nets.

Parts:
C1, C2: 10uF; C_0805_2012Metric_Pad1.15x1.40mm_HandSolder
C3, C4, C5: 100nF; C_0603_1608Metric_Pad1.05x0.95mm_HandSolder
J1: Conn_02x10_Odd_Even; PinHeader_2x10_P2.54mm_Vertical
R1: 100Ohm; R_0805_2012Metric_Pad1.15x1.40mm_HandSolder
U1: VIC-IIe; socket_embedded_48pin
U2: MIC5504-3.3YM5; SOT-23-5
U3: LVC257; TSSOP-16_4.4x5mm_P0.65mm
U4, U5: LVC245; TSSOP-20_4.4x6.5mm_P0.65mm

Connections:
+3V3: C2.1, C3.1, C4.1, C5.1, U2.5, U3.16, U4.1, U4.20, U5.1, U5.20
+5V: C1.1, U1.48, U2.1, U2.3
A0: J1.14, U5.17
A1: J1.13, U5.18
AEC: J1.18, U3.1, U5.13
BA: J1.17, U5.14
CS: J1.15, U5.16
DB0: J1.8, U4.11
DB1: J1.7, U4.12
DB2: J1.6, U4.13
DB3: J1.5, U4.14
DB4: J1.4, U4.15
DB5: J1.3, U4.16
DB6: J1.2, U4.17
DB7: J1.1, U4.18
DB8_A2: J1.12, U3.9
DB9_A3: J1.11, U3.7
DB10_A4: J1.10, U3.12
DB11_A5: J1.9, U3.4
GND: C1.2, C2.2, C3.2, C4.2, C5.2, J1.19, U1.24, U2.2, U3.8, U3.15, U4.10, U4.19, U5.8, U5.10, U5.19
unnamed: R1.2, U5.11
unnamed: U1.1, U4.3
unnamed: U1.2, U4.4
unnamed: U1.3, U4.5
unnamed: U1.4, U4.6
unnamed: U1.5, U4.7
unnamed: U1.6, U4.8
unnamed: U1.7, U4.9
unnamed: U1.10, U5.6
unnamed: U1.12, U5.7
unnamed: U1.13, U5.4
unnamed: U1.14, U5.5
unnamed: U1.18, U5.9
unnamed: U1.32, U5.3
unnamed: U1.33, U5.2
unnamed: U1.34, U3.10
unnamed: U1.35, U3.6
unnamed: U1.36, U3.13
unnamed: U1.37, U3.3
unnamed: U1.43, U3.2
unnamed: U1.44, U3.14
unnamed: U1.45, U3.5
unnamed: U1.46, U3.11
unnamed: U1.47, U4.2
PHI0: J1.20, R1.1
RW: J1.16, U5.15

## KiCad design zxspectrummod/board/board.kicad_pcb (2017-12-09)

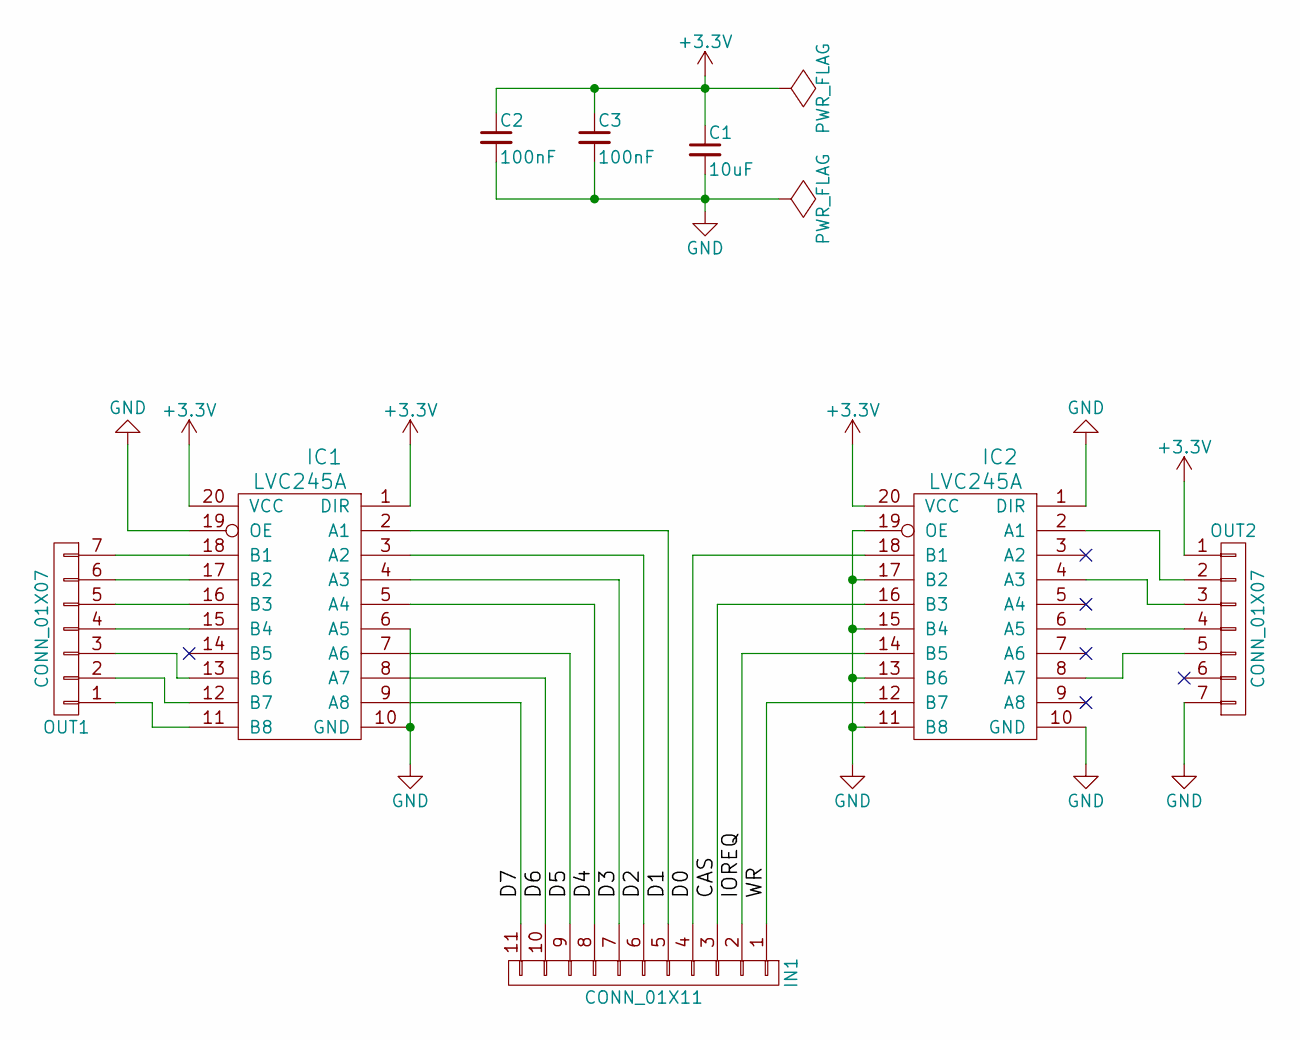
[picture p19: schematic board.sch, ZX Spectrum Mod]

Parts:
C1: 10uF; C_0805_HandSoldering
C2, C3: 100nF; C_0603_HandSoldering
IC1, IC2: LVC245A; SOIC-20W_7.5x12.8mm_Pitch1.27mm
IN1: CONN_01X11; Pin_Header_Straight_1x11_Pitch2.54mm
OUT1, OUT2: CONN_01X07; Pin_Header_Straight_1x07_Pitch2.54mm

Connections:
+3V3: C1.1, C2.1, C3.1, IC1.1 (DIR), IC1.20 (VCC), IC2.20 (VCC), OUT2.1
/CAS: IC2.16 (B3), IN1.3
/D0: IC2.18 (B1), IN1.4
/D1: IC1.2 (A1), IN1.5
/D2: IC1.3 (A2), IN1.6
/D3: IC1.4 (A3), IN1.7
/D4: IC1.5 (A4), IN1.8
/D5: IC1.7 (A6), IN1.9
/D6: IC1.8 (A7), IN1.10
/D7: IC1.9 (A8), IN1.11
/IOREQ: IC2.14 (B5), IN1.2
/WR: IC2.12 (B7), IN1.1
GND: C1.2, C2.2, C3.2, IC1.6 (A5), IC1.10 (GND), IC1.19 (OE), IC2.1 (DIR), IC2.10 (GND), IC2.11 (B8), IC2.13 (B6), IC2.15 (B4), IC2.17 (B2), IC2.19 (OE), OUT2.7
unnamed: IC1.11 (B8), OUT1.1
unnamed: IC1.12 (B7), OUT1.2
unnamed: IC1.13 (B6), OUT1.3
unnamed: IC1.15 (B4), OUT1.4
unnamed: IC1.16 (B3), OUT1.5
unnamed: IC1.17 (B2), OUT1.6
unnamed: IC1.18 (B1), OUT1.7
unnamed: IC2.2 (A1), OUT2.2
unnamed: IC2.4 (A3), OUT2.3
unnamed: IC2.6 (A5), OUT2.4
unnamed: IC2.8 (A7), OUT2.5

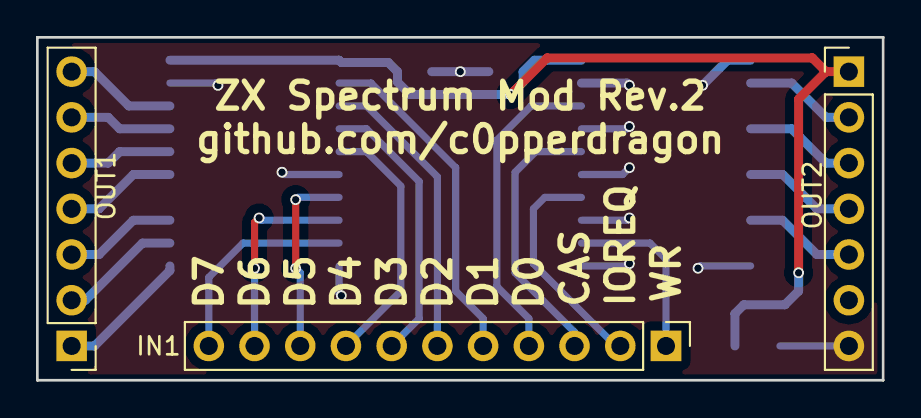
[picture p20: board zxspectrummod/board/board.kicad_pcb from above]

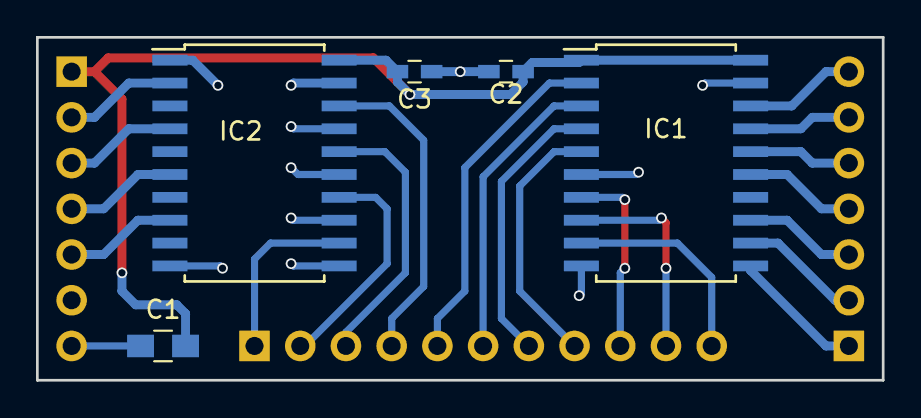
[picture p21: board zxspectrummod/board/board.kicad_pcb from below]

Board: 2 copper layers, 47.0 x 19.0 mm, 8 parts (5 on the bottom side), 24 nets.

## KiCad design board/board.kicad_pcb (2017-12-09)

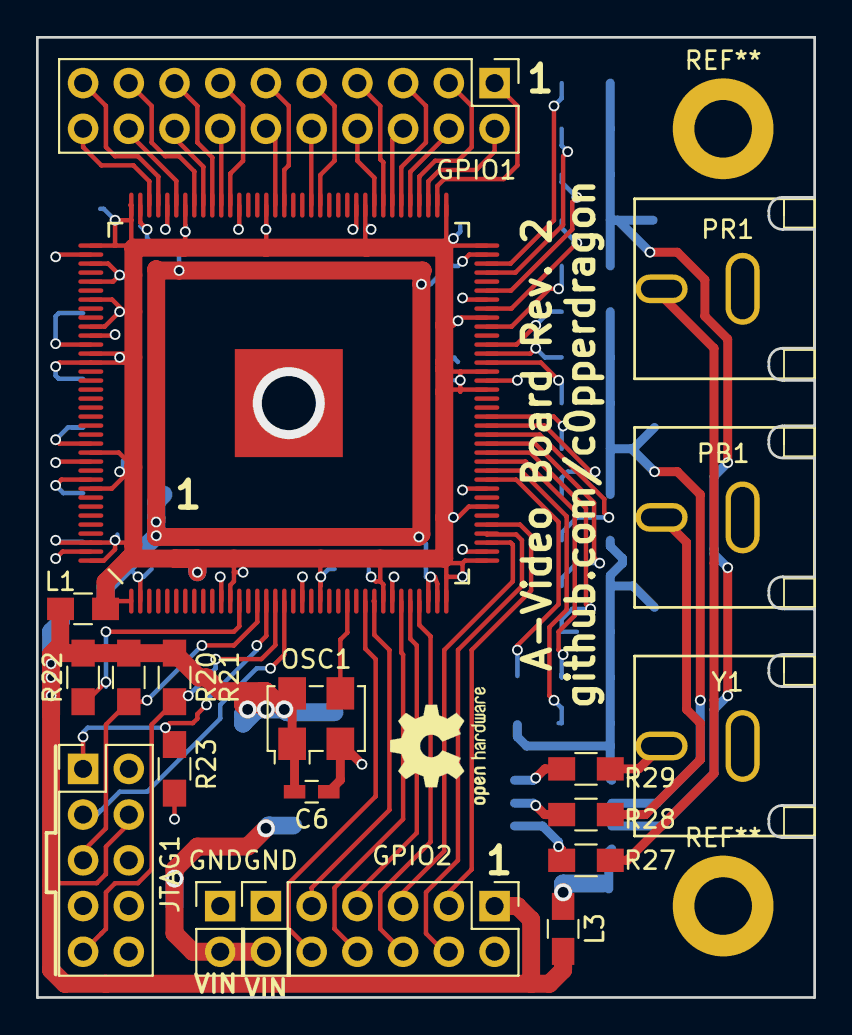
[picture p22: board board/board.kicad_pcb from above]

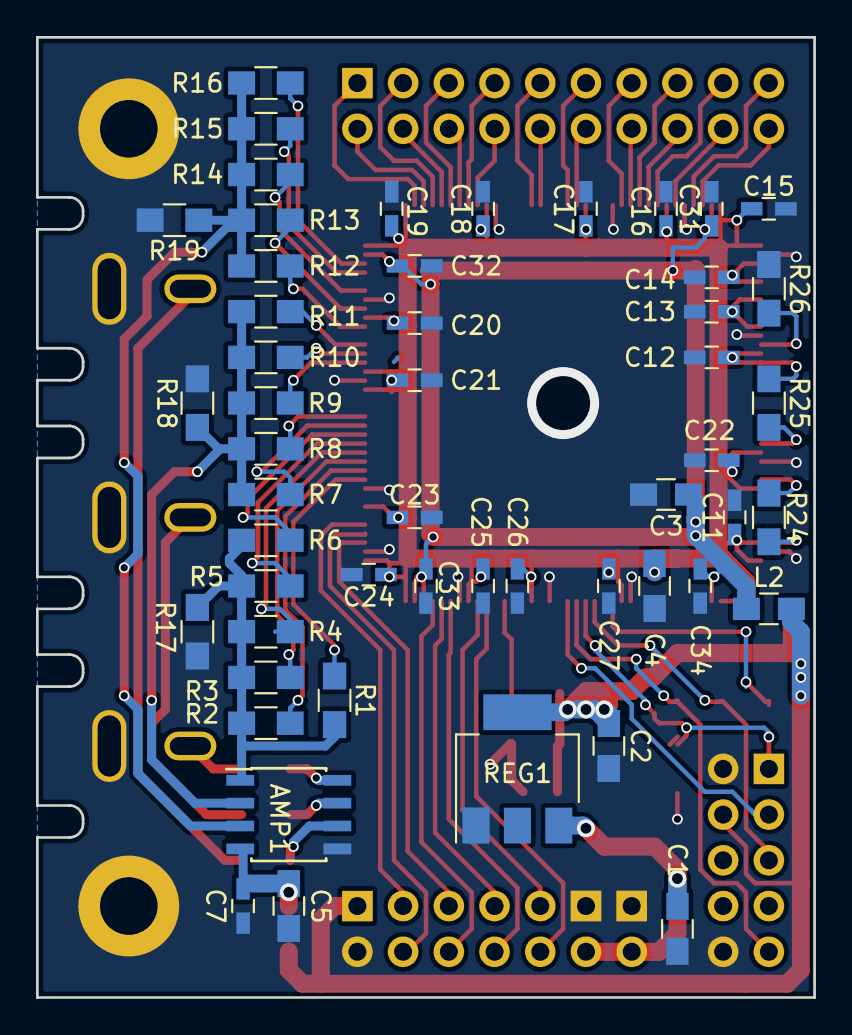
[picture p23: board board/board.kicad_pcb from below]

Board: 2 copper layers, 43.2 x 53.3 mm, 72 parts (52 on the bottom side), 68 nets.

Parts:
AMP1: THS7316; SOIC-8_3.9x4.9mm_Pitch1.27mm
C1, C2, C3, C4, C5: 10uF; C_0805_HandSoldering
C6, C7, C11, C12, C13, C14, C15, C16, C17, C18, C19, C20, C21, C22, C23, C24, C25, C26, C27, C31, C32, C33, C34: 100nF; C_0603_HandSoldering
GND: CONM_01x02; Pin_Header_Straight_1x02_Pitch2.54mm
GND#2: CONN_02X01; Pin_Header_Straight_1x02_Pitch2.54mm
GPIO1: CONN_02X10; Pin_Header_Straight_2x10_Pitch2.54mm
GPIO2: CONN_02X05; Pin_Header_Straight_2x05_Pitch2.54mm
JTAG1: CONN_02X05; Pin_Header_Straight_2x05_Pitch2.54mm
L1, L2, L3: 10mH; C_0805_HandSoldering
OSC1: LFSPXO024957; Oscillator_SMD_EuroQuartz_XO53-4pin_5.0x3.2mm_HandSoldering
PB1: BNC; RCA_JACK
PR1: BNC; RCA_JACK
R1: 1k1; R_0805_HandSoldering
R2, R7, R12: 1k; R_0805_HandSoldering
R3, R8, R13: 2k; R_0805_HandSoldering
R4, R9, R14: 4k; R_0805_HandSoldering
R5, R10, R15: 8k; R_0805_HandSoldering
R6, R11, R16: 16k; R_0805_HandSoldering
R17, R18, R19: 150; R_0805_HandSoldering
R20, R21, R22, R23, R24, R25, R26: 10k; R_0805_HandSoldering
R27, R28, R29: 75; R_0805_HandSoldering
REG1: LM1117IMPX-3.3; SOT-223
U2: 10M02SCE144; QFP_144_GND
Y1: BNC; RCA_JACK

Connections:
/3V3A: C2.1, C6.1, GPIO2.1, JTAG1.4, L1.2, L2.2, L3.2, OSC1.1, OSC1.4, R20.2, R21.2, R22.2, REG1.4
/3V3B: C4.1, C11.1, C12.1, C13.1, C14.1, C15.1, C16.1, C17.1, C18.1, C19.1, C20.1, C21.1, C22.1, C23.1, C24.1, C25.1, C26.1, C27.1, L1.1, R24.1, R25.1, U2.1, U2.12, U2.22, U2.29, U2.36, U2.37, U2.43, U2.56, U2.58, U2.64, U2.72, U2.73, U2.82, U2.93, U2.102, U2.108, U2.109, U2.111, U2.113, U2.115, U2.118, U2.121, U2.122, U2.132, U2.136, U2.142, U2.144
/3V3C: C3.1, C31.1, C32.1, C33.1, C34.1, L2.1, U2.2, U2.34, U2.35, U2.71, U2.107
/3V3D: AMP1.4, C5.1, C7.2, L3.1
GND: AMP1.5, C1.2, C2.2, C3.2, C4.2, C5.2, C6.2, C7.1, C11.2, C12.2, C13.2, C14.2, C15.2, C16.2, C17.2, C18.2, C19.2, C20.2, C21.2, C22.2, C23.2, C24.2, C25.2, C26.2, C27.2, C31.2, C32.2, C33.2, C34.2, GND.1, GND#2.1, GPIO2.2, JTAG1.2, JTAG1.10, OSC1.2, PB1.2, PR1.2, R17.2, R18.2, R19.2, R23.1, R26.1, REG1.1, U2.11, U2.20, U2.30, U2.38, U2.45, U2.57, U2.66, U2.83, U2.96, U2.104, U2.110, U2.119, U2.133, U2.143, U2.145, Y1.2
unnamed: AMP1.1, R1.2, R2.2, R3.2, R4.2, R5.2, R6.2, R17.1
unnamed: AMP1.2, R7.2, R8.2, R9.2, R10.2, R11.2, R18.1
unnamed: AMP1.3, R12.2, R13.2, R14.2, R15.2, R16.2, R19.1
unnamed: AMP1.6, R27.2
unnamed: AMP1.7, R28.2
unnamed: AMP1.8, R29.2
unnamed: C1.1, GND.2, GND#2.2, REG1.3
unnamed: GPIO1.1, U2.74
unnamed: GPIO1.2, U2.75
unnamed: GPIO1.3, U2.76
unnamed: GPIO1.4, U2.77
unnamed: GPIO1.5, U2.78
unnamed: GPIO1.6, U2.79
unnamed: GPIO1.7, U2.80
unnamed: GPIO1.8, U2.81
unnamed: GPIO1.9, U2.87
unnamed: GPIO1.10, U2.88
unnamed: GPIO1.11, U2.91
unnamed: GPIO1.12, U2.92
unnamed: GPIO1.13, U2.97
unnamed: GPIO1.14, U2.98
unnamed: GPIO1.15, U2.99
unnamed: GPIO1.16, U2.100
unnamed: GPIO1.17, U2.101
unnamed: GPIO1.18, U2.103
unnamed: GPIO1.19, U2.105
unnamed: GPIO1.20, U2.106
unnamed: GPIO2.3, U2.41
unnamed: GPIO2.4, U2.40
unnamed: GPIO2.5, U2.39
unnamed: GPIO2.6, U2.33
unnamed: GPIO2.7, U2.32
unnamed: GPIO2.8, U2.31
unnamed: GPIO2.9, U2.28
unnamed: GPIO2.10, U2.27
unnamed: JTAG1.1, R23.2, U2.16
unnamed: JTAG1.3, U2.18
unnamed: JTAG1.5, R20.1, U2.15
unnamed: JTAG1.9, R21.1, U2.17
unnamed: OSC1.3, U2.25
unnamed: PB1.1, R28.1
unnamed: PR1.1, R27.1
unnamed: R1.1, U2.46
unnamed: R2.1, U2.47
unnamed: R3.1, U2.48
unnamed: R4.1, U2.49
unnamed: R5.1, U2.50
unnamed: R6.1, U2.51
unnamed: R7.1, U2.52
unnamed: R8.1, U2.53
unnamed: R9.1, U2.59
unnamed: R10.1, U2.60
unnamed: R11.1, U2.61
unnamed: R12.1, U2.63
unnamed: R13.1, U2.65
unnamed: R14.1, U2.67
unnamed: R15.1, U2.69
unnamed: R16.1, U2.70
unnamed: R22.1, U2.13
unnamed: R24.2, U2.135
unnamed: R25.2, U2.131
unnamed: R26.2, U2.120
unnamed: R29.1, Y1.1

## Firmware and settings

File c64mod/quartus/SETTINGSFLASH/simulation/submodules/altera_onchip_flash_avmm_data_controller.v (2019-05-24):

// (C) 2001-2018 Intel Corporation. All rights reserved.
// Your use of Intel Corporation's design tools, logic functions and other 
// software and tools, and its AMPP partner logic functions, and any output 
// files from any of the foregoing (including device programming or simulation 
// files), and any associated documentation or information are expressly subject 
// to the terms and conditions of the Intel Program License Subscription 
// Agreement, Intel FPGA IP License Agreement, or other applicable 
// license agreement, including, without limitation, that your use is for the 
// sole purpose of programming logic devices manufactured by Intel and sold by 
// Intel or its authorized distributors.  Please refer to the applicable 
// agreement for further details.


////////////////////////////////////////////////////////////////////
//
//  ALTERA_ONCHIP_FLASH_AVMM_DATA_CONTROLLER (PARALLEL-to-SERIAL MODE)
//
//  Copyright (C) 1991-2013 Altera Corporation
//  Your use of Altera Corporation's design tools, logic functions 
//  and other software and tools, and its AMPP partner logic 
//  functions, and any output files from any of the foregoing 
//  (including device programming or simulation files), and any 
//  associated documentation or information are expressly subject 
//  to the terms and conditions of the Altera Program License 
//  Subscription Agreement, Altera MegaCore Function License 
//  Agreement, or other applicable license agreement, including, 
//  without limitation, that your use is for the sole purpose of 
//  programming logic devices manufactured by Altera and sold by 
//  Altera or its authorized distributors.  Please refer to the 
//  applicable agreement for further details.
//
////////////////////////////////////////////////////////////////////

// synthesis VERILOG_INPUT_VERSION VERILOG_2001

`timescale 1 ps / 1 ps

module altera_onchip_flash_avmm_data_controller (
    // To/From System
    clock,
    reset_n,
    
    // To/From Flash IP interface
    flash_busy,
    flash_se_pass,
    flash_sp_pass,
    flash_osc,
    flash_drdout,
    flash_xe_ye,
    flash_se,
    flash_arclk,
    flash_arshft,
    flash_drclk,
    flash_drshft,
    flash_drdin,
    flash_nprogram,
    flash_nerase,
    flash_ardin,
        
    // To/From Avalon_MM data slave interface
    avmm_read,
    avmm_write,
    avmm_addr,
    avmm_writedata,
    avmm_burstcount,
    avmm_waitrequest,
    avmm_readdatavalid,
    avmm_readdata,
        
    // To/From Avalon_MM csr slave interface
    csr_control,
    csr_status
);

    parameter READ_AND_WRITE_MODE = 0;
    parameter WRAPPING_BURST_MODE = 0;
    parameter DATA_WIDTH = 32;
    parameter AVMM_DATA_ADDR_WIDTH = 20;
    parameter AVMM_DATA_BURSTCOUNT_WIDTH = 4;
    parameter FLASH_ADDR_WIDTH = 23;
    parameter FLASH_SEQ_READ_DATA_COUNT = 2;    //number of 32-bit data per sequential read
    parameter FLASH_READ_CYCLE_MAX_INDEX = 3;    //period to for each sequential read
    parameter FLASH_ADDR_ALIGNMENT_BITS = 1;     //number of last addr bits for alignment
    parameter FLASH_RESET_CYCLE_MAX_INDEX = 28;    //period that required by flash before back to idle for erase and program operation
    parameter FLASH_BUSY_TIMEOUT_CYCLE_MAX_INDEX = 112; //flash busy timeout period (960ns)
    parameter FLASH_ERASE_TIMEOUT_CYCLE_MAX_INDEX = 40603248; //erase timeout period (350ms)
    parameter FLASH_WRITE_TIMEOUT_CYCLE_MAX_INDEX = 35382; //write timeout period (305us)
    parameter MIN_VALID_ADDR = 1;
    parameter MAX_VALID_ADDR = 1;
    parameter SECTOR1_START_ADDR = 1;
    parameter SECTOR1_END_ADDR = 1;
    parameter SECTOR2_START_ADDR = 1;
    parameter SECTOR2_END_ADDR = 1;
    parameter SECTOR3_START_ADDR = 1;
    parameter SECTOR3_END_ADDR = 1;
    parameter SECTOR4_START_ADDR = 1;
    parameter SECTOR4_END_ADDR = 1;
    parameter SECTOR5_START_ADDR = 1;
    parameter SECTOR5_END_ADDR = 1;
    parameter SECTOR_READ_PROTECTION_MODE = 5'b11111;
    parameter SECTOR1_MAP = 1;
    parameter SECTOR2_MAP = 1;
    parameter SECTOR3_MAP = 1;
    parameter SECTOR4_MAP = 1;
    parameter SECTOR5_MAP = 1;
    parameter ADDR_RANGE1_END_ADDR = 1;
    parameter ADDR_RANGE2_END_ADDR = 1;
    parameter ADDR_RANGE1_OFFSET = 1;
    parameter ADDR_RANGE2_OFFSET = 1;
    parameter ADDR_RANGE3_OFFSET = 1;
    
    localparam [1:0]    ERASE_ST_IDLE = 0,
                        ERASE_ST_PENDING = 1,
                        ERASE_ST_BUSY = 2;

    localparam [1:0]    STATUS_IDLE = 0,
                        STATUS_BUSY_ERASE = 1,
                        STATUS_BUSY_WRITE = 2,
                        STATUS_BUSY_READ = 3;
    
    // State 0~4 is common for both RW and read only mode. State 5~8 is only needed in RW mode.
    localparam [3:0]    OP_STATE_IDLE = 0,
                        OP_STATE_ADDR = 1,
                        OP_STATE_READ_SHIFT = 2,
                        OP_STATE_READ_DATA = 3,
                        OP_STATE_CLEAR = 4,
                        OP_STATE_WRITE = 5,
                        OP_STATE_WAIT_BUSY = 6,
                        OP_STATE_WAIT_DONE = 7,
                        OP_STATE_RESET = 8;

    // To/From System
    input clock;
    input reset_n;
    
    // To/From Flash IP interface
    input flash_busy;
    input flash_se_pass;
    input flash_sp_pass;
    input flash_osc;
    input [DATA_WIDTH-1:0] flash_drdout;
    output flash_xe_ye;
    output flash_se;
    output flash_arclk;
    output flash_arshft;
    output flash_drclk;
    output flash_drshft;
    output flash_drdin;
    output flash_nprogram;
    output flash_nerase;
    output [FLASH_ADDR_WIDTH-1:0] flash_ardin;
        
    // To/From Avalon_MM data slave interface
    input avmm_read;
    input avmm_write;
    input [AVMM_DATA_ADDR_WIDTH-1:0] avmm_addr;
    input [DATA_WIDTH-1:0] avmm_writedata;
    input [AVMM_DATA_BURSTCOUNT_WIDTH-1:0] avmm_burstcount;
    output avmm_waitrequest;
    output avmm_readdatavalid;
    output [DATA_WIDTH-1:0] avmm_readdata;
        
    // To/From Avalon_MM csr slave interface
    input [31:0] csr_control;
    output [9:0] csr_status;

    reg reset_n_reg1;
    reg reset_n_reg2;
    reg flash_busy_reg;
    reg flash_busy_clear_reg;
    reg flash_addr_neg_reg;
    reg flash_drdin_neg_reg;
    reg [DATA_WIDTH-1:0] flash_drdout_neg_reg;
    reg [AVMM_DATA_BURSTCOUNT_WIDTH-1:0] cur_burstcount;
    reg [1:0] csr_status_busy;
    reg csr_status_e_pass;
    reg csr_status_w_pass;
    reg csr_status_r_pass;

    reg [3:0] op_state;
    reg op_wait;
    reg op_r_wait;
    reg op_wait_neg_reg;
    reg op_count_start;
    reg op_w_count_start;
    reg [FLASH_ADDR_WIDTH-1:0] op_addr;
    reg op_wrap_back_addr;
    reg op_range2_addr;
    reg op_range3_addr;
    reg op_illegal_write_addr;
    reg op_scan_busy;
    
    reg arclk_en;
    reg enable_arclk_neg_reg;
    reg enable_arclk_neg_pos_reg;
    reg enable_drclk_neg_reg;
    reg enable_drclk_neg_pos_reg;
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

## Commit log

2017-10-08 Start to design the board
    First created the FPGA element in KiCad
    [board.kicad_pcb, board.sch]
2017-10-14 Play with the 50Hz and 60Hz modes to get a centered picture
2017-10-15 Schematics and Start of Board Layout
    [board.kicad_pcb, board.sch, resistors.ods]
2017-10-20 Board layout finished
    [board.kicad_pcb, board.sch]
2017-10-26 Adapter board for ZX Spectrum
    Plus some changes to the A-Video board itself to better fit the needs of
    the ZX Spectrum mod (which currently drives the development)
    [board.kicad_pcb, board.sch]
2017-10-27 small additions for zx spectrum mod
    [board.kicad_pcb, board.sch]
2017-11-01 gerber files for PCB manufacture
    [board.kicad_pcb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]
2017-12-03 Complete redo of the board
    In Rev.1 I got GND and Line mixed up for the Video line sockets. As I
    had to modify the board anyway, I also changed the location of the FPGA
    from backside to front side and therefore had to redo everything.
    [board.kicad_pcb, board.sch]
2017-12-08 finalize board layout
    [board.kicad_pcb]
2017-12-09 created gerber files
    [board-B.Cu.gbl, board-B.Mask.gbs, board-B.SilkS.gbo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]
2017-12-09 Redesign ZX Spectrum Mod
    To match the Rev.2 A-Video board
    [board-B.Cu.gbr, board-B.Mask.gbr, board-B.SilkS.gbr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]
2017-12-12 atari mod and adapter
    [adapterboard-B.Cu.gbr, adapterboard-B.Mask.gbr, adapterboard-B.SilkS.gbr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]
2018-01-21 Modifed programs for A-Video Board Rev.2
    Finally got the PCB for the Rev.2. Assembled the board and everything
    worked at first try :-)
    [board.sch]
2018-02-08 Fixed a bug in the board layout
    Working version now on Atari 800XL.
    But in the mod board that needed some botching. Fixed in schematic and
    layout. Removed buggy gerber files.
    [atarimod-B.Cu.gbr, atarimod-B.Mask.gbr, atarimod-B.SilkS.gbr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]
2018-02-18 A-Video Board schematics and bill of material
2018-03-10 Tweek colors and sprite dma
    But I still have no idea how GTIA 9-color mode interacts with p/m
    graphics....
2018-05-27 start development of C64 converter box
    [c64converter.kicad_pcb, c64converter.sch]
2018-05-29 Layout of C64 converter board
    [c64converter.sch]
2018-05-31 Finished c64converter layout and gerber files
    [c64converter-B.Cu.gbr, c64converter-B.Mask.gbr, c64converter-B.SilkS.gbr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]
2018-07-19 New attempt for the C64, using a three-channel ADC on 7.88 Mhz
2018-08-24 C64 adapter board
    New attempt to get the video signal by emulating the VIC II digitally (like for the Atari 800 and the ZX Spectrum)
    [c64board.kicad_pcb, c64board.sch]
2018-08-25 Finished C64 mod board
    generate gerber files also for Rev. 1
    [c64board-B.Cu.gbr, c64board-B.Mask.gbr, c64board-B.SilkS.gbr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]
2018-10-19 Redisign sprite activity detection
    [c64converter-B.Cu.gbr, c64converter-B.Mask.gbr, c64converter-B.SilkS.gbr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]
2018-10-25 Frame synchronization
    Use the dram refresh signal anomaly to find the start of the frame.
    Improved palette and scan line generation.
2018-10-29 Reverse connector orientation
    [c64board.kicad_pcb, c64board.sch]
2018-11-03 Finer clock synchronization for Atari mod
    Reworked the high-res clock generation.
    Will probably work with NTSC machines also (pixel clock is very similar to PAL) and they have same number of pixels per line.
    For true NTSC compatibility, I would need a test device for development.
2018-11-07 "Improvement"
    Somehow messed up sprite 4 DMA while improving clock accurracy.
    Either I will find the problem someday or I will just revert the whole thing...
2018-12-09 Integrated RF modulator replacement
    Designing a special A-Video board that can replace the RF modulator in the C64 (all models) and provide the usual signals on the A/V jack, and also the YPbPr signal.
    [rfreplacement-2018-12-04-19-31-54.sch, rfreplacement.sch]
2018-12-10 rf-replacment: pcb layout
    [rfreplacement.kicad_pcb, rfreplacement.sch]
2018-12-18 C64 mod: fit rf replacement to long and short main boards
    [rfreplacement.kicad_pcb, rfreplacement.sch]
2018-12-22 Layout RF replacement board
    [rfreplacement.kicad_pcb, rfreplacement.sch]
2019-01-10 Finished RF replacement board for C64
    [rfreplacement-B.Cu.gbr, rfreplacement-B.Mask.gbr, rfreplacement-B.SilkS.gbr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]
2019-02-07 Moved rfreplacment to extra project, rearrange firmeware to make NTSC easier
    [rfreplacement-2018-12-04-19-31-54.sch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]
2019-03-12 Update gerber files
    [c64board-B.Cu.gbr, c64board-B.Mask.gbr, c64board-B.SilkS.gbr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]
2019-04-25 Modified C64 VIC adapter for easier manufacture
    [c64board-B.Cu.gbr, c64board-B.Mask.gbr, c64board-B.SilkS.gbr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]
2019-04-28 C64 mod: Reducing code size
    Rework the firmware to make the code smaller and clearer. Reducing current size may later allow additonal features...
2019-05-16 Color blending
    The color generator now uses a 16x16 matrix to combine the colors of two subsequent lines. By default the color depends on just the current line, but the colors and be personalized to create blending.
    Additinally tweeked the digital signal path speed to better match the analog signal.
2019-05-24 Unlocking settings mode
    To unlock set color settings mode, you now need to write 137 into register 53311, as well as toggle the mode switch once.
    Additionaly fixed DMA fetch of sprite 0 on PAL
2019-06-07 Simplified sprite DMA and sequencing
2019-06-07 Start up with black screen
    To avoid having ugly data garbage on the screen after switching on the C64, the background and border colors are set to black until the CPU changes them.
2019-06-07 Better detection of sprite DMA
2019-06-14 Idle mode working correctly in lower border
    As it turns out, the video matrix fetch and the pixel sequencer are controlled by the vertical border flip-flop.
    Now the simulation seems pretty complete.
    (also did update the built-in IPs to the new quartus version)
    [SETTINGSFLASH.csv]
2019-06-19 Tweak non-sprite display
    Using all of the tests available on the win-vice testbench, I nearly got everything right now that is not sprite related. Specifially video mode switching is not 100% accurate, but the real VIC varia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
2019-07-05 Shifted sample point for ram refresh detection
2019-07-30 Tiny tweak of sample timing
2019-08-14 Add BOM
    [adapterboard_bom.ods]
2019-08-14 Fix docu
    [adapterboard_bom.ods]
2019-08-15 Move gerber files to documentation folder
2019-09-28 Reduce signal jitter
2020-01-31 Adapter for the C128
    [c128board.kicad_pcb, c128board.sch]
2020-01-31 Bill of material, more docu
    [c128adapter_bom.ods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]
2020-06-17 Try to get compatibility with PAL-N and PAL-M devices.
2020-07-22 Revision 3 of Atari GTIA Adapter
    [adapterboard-B.Cu.gbr, adapterboard-B.Mask.gbr, adapterboard-B.SilkS.gbr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]
2020-07-22 Test pattern generator can switch output mode
2020-07-27 Fixed player 4 DMA bug. Update to new quartus version.
2020-08-01 Try a tiny additional tweak for the sprite DMA detection.
2020-08-01 More blind testing of sprite DMA
2020-08-01 Add solder switch option to hard-set the sprite dma timing
2020-08-16 New method to detect sprite DMA, which is no longer depending on exact timing.
2020-08-17 Use async methods better to catch the address activity during sprite DMA
2020-08-17 Further attempts to tweak the sprite DMA detection...
2020-08-22 Move sprite DMA by one cycle for 6567R56A mode
2020-09-01 Finally fixed the sprite DMA problem, which was very noticable in the "Video Worm" demo.
2020-09-13 Keep trying to find the best sample points...
2020-09-15 Use different voltage regulator to reduce noise
    [atarimod.kicad_pcb, atarimod.sch]
2021-05-25 Experimental firmware with delayed register data sample point
2023-05-22 Fix sample sequencer
